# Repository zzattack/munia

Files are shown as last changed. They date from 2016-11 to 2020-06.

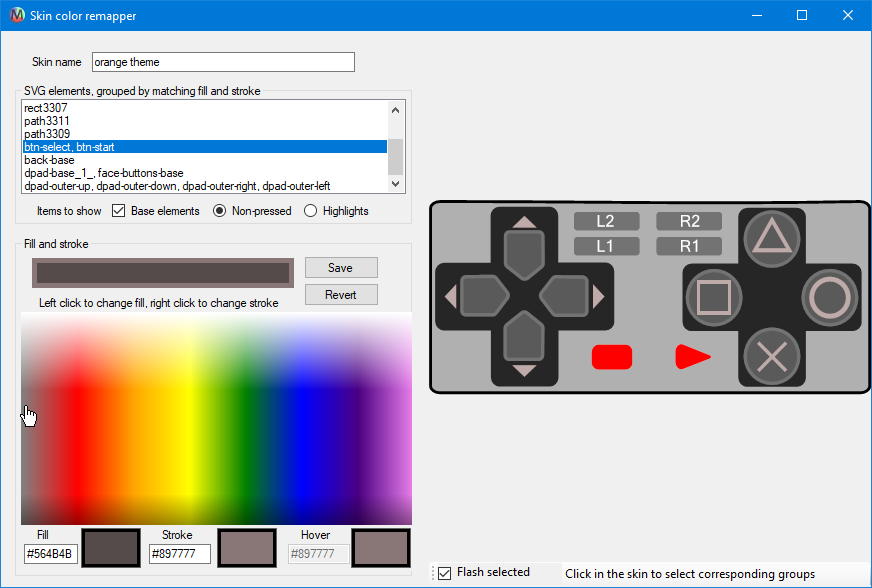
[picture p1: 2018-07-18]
munia_io/static_global/img/content/remap_engine.png

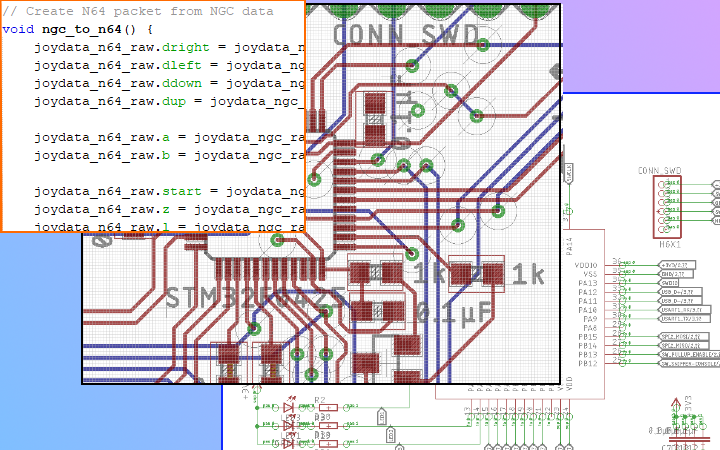
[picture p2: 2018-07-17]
munia_io/static_global/img/content/opensource.png

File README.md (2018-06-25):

MUNIA is a device that acquires input packets from controllers of various videogame consoles and shows them on your PC with the controller simultaneously remaining attached to its console. This allows you to display your inputs on gameplay videos or livestream content.
Devices for several consoles have been developed under this project:
* Nintendo Gamecube
* Sony Playstation 2
* Nintendo 64
* Super Nintendo

# Repository overview
* The hardware folder contains schematics for the various devices developed under this project. These include input adapters for Nintendo Gamecube, Nintendo 64, Super Nintendo, Sony PlayStation 2 and hybrids of the aforementioned.
* The firmware folder contains firmware projects for each of the circuit boards presented in the hardware folder.
* The munia.io folder contains the Django project powering the http://munia.io website (not functional).
* The MUNIA-win folder contains the .NET project 

## FAQ
Q. I don’t like the default skins, can I change them?
Absolutely. The software has a very strong SVG based theming engine. You can create a new one using tools like Adobe Illustrator or Inkscape. Custom XML attributes are used to map buttons to graphical elements. It’s pretty simple, honestly; take a look in SKINS.md!

Q. What does ‘MUNIA’ mean?
The very first iteration of the device supported SNES, N64 and NGC simultaneously. The acronym stands for ‘Multi-use Nintendo Input Adapter’. Both the Multi-use and Nintendo parts no longer apply to most of our devices, so we’ve parted with the acronym but kept the pretty name.

Q. Will you support console ‘X’?
Unless mentioned on the index page, the likely answer is no. Newer generation consoles are usually too complicated. The low expected demand for adapters for older generation consoles doesn’t warrant the required development investments at the moment.

Q. How does this compare to an Arduino input display?
Favorably. Benefits include not having to splice any cables, the device showing up as HID device on your computer, superior software, more stable firmware, ability to use the controller on our PC in e.g. emulators and better 3rd party controller support. In the end, though, both work and the MUNIA software also supports inputs from Arduino-based NintendoSpy devices!

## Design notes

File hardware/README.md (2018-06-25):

# This folder contains the EAGLE schematics for the various hardware boards.

## munia
This contains schematics and board layout for the 3-in-1 device with support for the Nintendo Gamecube, Nintendo 64 and Super Nintendo/SFC consoles.
The enclosure also makes use of the 

## munia-ngc
This is the simplified Gamecube-only version of the device

## munia-n64
This is the simplified N64-only version of the device

## munia-snes
This is the simplified SNES-only version of the device

## musia
This is the Sony PS2 version

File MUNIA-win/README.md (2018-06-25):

This is the .NET software which uses SVG skins and OpenGL rendering to make a powerful controller overlay for videogame streaming

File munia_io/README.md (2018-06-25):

# munia.io

These are the django project files powering the http://munia.io website.

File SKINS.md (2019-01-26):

# MUNIA skinning

Skins for MUNIA are defined as SVG files with some custom attributes mixed in to identify and animate various controller parts.
Benefits of using SVG files include perfect scaling, self-contained files and ability to use high quality image editing software such as Adobe Illustrator or [Inkscape](https://inkscape.org/).

## Process overview
1. *Find base image:* when adopting a new skin one typically begins by finding an existing image of the desired controller. For many popular controllers well-built SVG files may already exist. Should this not be the case then tracing a high quality image of said controller is a viable alternative.

2. *Add highlights:* button presses are typically shown by changing the color of said button, but MUNIA allows a lot of freedom in this aspect. Per button you normally define 2 object groups, one for the non-pressed and one for the pressed state of this button. They will typically overlap exactly, but this is not mandatory. The MUNIA software will show only one of both states at a time.

3. *Add metadata:* the last step is to add some XML attributes to the resulting .svg file. These will allow the MUNIA software to identify the various parts of the controller, and thereby animate them in the desired way. Full details on the possible attributes to specify are detailed in the sections below.

## Skin engine
The MUNIA skinning engine initially loads the SVG file, identifies the various parts in it, and caches the drawing of most individual elements. The controller with all button, stick and trigger elements removed is used as base image. All elements are continuously rendered against this base image.

### Layering
The controller is rendered as a layered image. The base image is fixed at layer '0'. Individual elements can be placed 'behind' or 'in front' of the base by specifying the `munia:z-order=x` attribute on it, where `x` can be any integer. Elements placed at layer x<0 are placed behind the base image in order of incrementing `x`. Similarly elements with positive z-order are drawn on top of the base image, again in order of incrementing `x`.

## Skin elements
Game controllers typically contain 3 kinds of elements that require some form of animation: buttons, triggers and sticks. We also need one XML element to specify what kind of controller is defined in this file. The following sections outline how to model each of them in MUNIA skins.

### Info metadata
The root `svg` element in the resulting document should contain a `munia:info` element specifying a name for the skin and the device type it is compatible with. 
Example, taken from `gc.svg` that ships with the MUNIA software:
``` xml
<munia:info munia:skin-name="Gamecube" munia:device-type="NGC"/>
```
Supported device types at the time of writing are:
* NGC
* SNES
* N64
* PS2
* XInput

### Buttons/dpad
Buttons and d-pad directions are considered identical in the MUNIA software. This simplifies skinning them. These are the relevant XML attributes:
* `munia:button-id="X"`: this specifies which button links to this image element. Refer to the final section in this document for hints on finding the correct id.
* `munia:button-state="pressed/released"`: this indicates whether this element is supposed to be visible in the pressed or released state. Effectively the software replaces the image group with `munia:button-state="released"` for the one with `button-state="pressed"` group if both have matching `munia:button-id` attributes. If you specify only one of both, the other is simply never drawn.
* `munia:z-order="x `: see Layering section above

#### Example
Taken from the SNES skin `snes-light-blue.svg` skin that ships with the software:
``` xml
<circle id="A" munia:button-id="7" munia:button-state="released" cx="380" cy="125" r="25" style="fill:#4d4d4d"/>
<circle id="A-pressed" munia:button-id="7" munia:button-state="pressed" cx="380" cy="125" r="25" style="fill:#0000ff"/>
```

### Sticks
Sticks refer to the control sticks that made their appearance in the 5th generation of videogame consoles. They are typically represented as a graphic that moves its vertical and horizontal position relative to a resting point. Sticks may also be pressable in which case you should define the button-id and button-state attributes if you want to use a different graphic for the stick depending on whether or not it is pressed. The MUNIA software implements to following attributes for specifying how these are to be rendered:

* `munia:stick-id="id"`: indicates that this element is to be considered a stick, and assigns an id to it. The id should be any unique integer number.
* `munia:axis-h="h" munia:axis-v="v"`: id's of the horizontal and vertical movement axes respectively. Refer to last section.
* `munia:offset-scale="f.f"`: a real/floating-point number indicating how far the stick moves away from its center. Good values are easily determined through trial and error. Typically a number between 0.5-2.0 should work well.
* `munia:button-id="x"`: see Buttons/dpad section above
* `munia:button-state="x"`: see Buttons/dpad section above. When using different graphics depending on the press-state, you should define the svg node describing the graphic twice; once for the pressed state and once for released. The graphic itself may of course differ in color, shape or structure.
* `munia:z-order="x"`: see Layering section above

#### Example
Taken from the Gamecube skin `gc.svg` skin that ships with the software:

``` xml
<g id="Control Stick" munia:axis-h="0" munia:axis-v="1" munia:offset-scale="1.8" transform="translate(8.6180222,-28.433458)"> ... </g>
```

### Triggers
The MUNIA software can render controller triggers as either a bar that fills up, or as an element that moves in certain direction.

* `munia:trigger-id="id"`: indicates that this element is to be considered a trigger, and assigns an id to it. The id should be any unique integer number.
* `munia:trigger-axis="x"`: id of this trigger axis on the controller. Refer to last section.
* `munia:trigger-range="a-b"`: specifies the deadzone. Defaults to '0-255' but can be limited, e.g. to '30-240' for controllers with imperfect range.
* `munia:trigger-type="bar/slide"`: whether this is rendered as a bar or slide. Bars are made partially visible, and slide-type triggers move some amount in one direction, depending on how far the trigger is pressed. 
* `munia:trigger-orientation="vertical/horizontal"`: whether the bar/slide is filled/moved in vertical or horizontal direction.
* `munia:trigger-reverse="yes/no"`: only applies to bar type triggers. When non-reversed (default), bars fill from left-to-right or top-to-bottom. Specifying `trigger-reverse="yes"` reverses that.
* `munia:trigger-inverse="yes/no"`: only applies to bar type triggers. Non-inversed triggers are 0% filled when the trigger is in resting state, and 100% filled when the trigger is entirely pressed. Inversing makes it so that not pressing the trigger reveals the entire object instead.
* `munia:offset-scale="f.f"`: applies only to *slide*-type triggers. Similar to the offset-scale attribute for sticks.
* `munia:z-order="x"`: see Layering section above

### Finding id's
One can easily find the id's of buttons and axes of a controller using the built-in `Gamepad tester` under `Tools` in the main menu.
Hat/dpad id's are mapped after the button id's, in order up/down/left/right. So if the controller has 6 face buttons and a d-pad, then the last face button has `button-id=5` and the left-direction on the d-pad is assigned `button-id=8`.

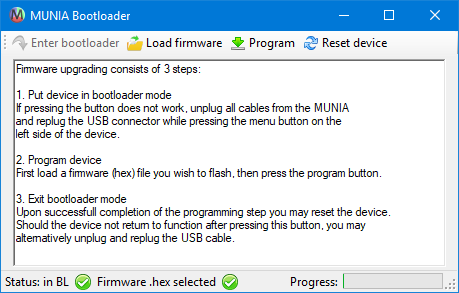
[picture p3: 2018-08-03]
munia_io/static_global/img/content/bootloader.png

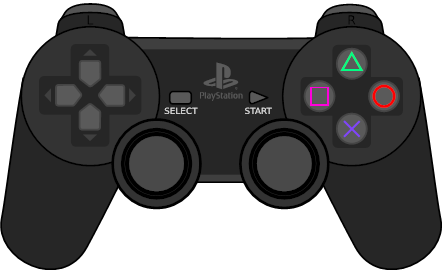
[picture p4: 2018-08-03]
munia_io/static_global/img/content/skin_ps2.png

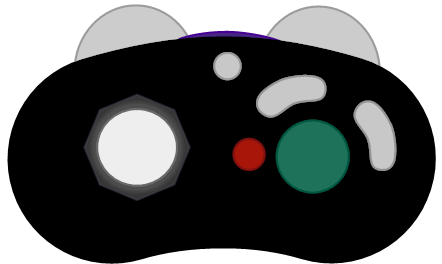
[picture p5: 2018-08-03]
munia_io/static_global/img/content/skin_gamecube_compact.png

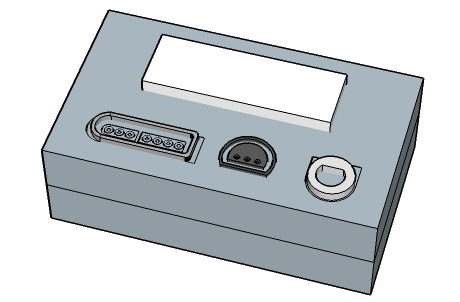
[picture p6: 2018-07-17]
munia_io/static_global/img/content/box.png

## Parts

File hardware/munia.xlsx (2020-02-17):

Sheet: components
Component | Fabrikant | Functie | Package | Datasheet
TXB0102DCUR | Texas Instruments | Level shifter | VSSOP | http://www.farnell.com/datasheets/1874809.pdf
PIC18LF24K50 | Microchip | Microcontroller | SSOP-28 | http://www.farnell.com/datasheets/1695243.pdf | x
TC1262 | Microchip | 3v3 regulator | SOT-223 | http://www.farnell.com/datasheets/1726424.pdf | x
BAT54S | NXP | Diode | SOT-23 | http://www.farnell.com/datasheets/1668625.pdf | x
BAT54C | NXP | Diode | SOT-24 | http://www.farnell.com/datasheets/1668625.pdf | x
TS3A24157DGSR | Texas Instruments | Mux | 10-MSOP | http://www.farnell.com/datasheets/1882551.pdf

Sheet: bom
Part | Quantity | Price | USB only version | Inventory | Ordered
lcd | 1 | $2.30 |  | 14 | 20
snes connector | 1 | $1.70 | $1.70 | 7 | 23
gc connector | 1 | $1.70 | $1.70 | 7 | 23
n64 connector | 1 | $1.70 | $1.70 | 7 | 23
output connector rj45 | 2 | $0.20 |  | 23 | 100
output connector rj12 | 1 | $0.20 |  | 42
usb connector | 1 | $0.20 | $0.20 | 40
pcb | 1 | $4.00 | $4.00 | 50
resistors / caps / diodes | 1 | $1.00 | $1.00 | 100
power diodes | 3 | $0.80 | $0.80 | 130
fsa2257 switch | 2 | $0.80 | $0.80 | 12 | 50
level converter gtl2010 | 1 | $0.55 | $0.55 | 38
microcontroller pic18 | 1 | $2.26 | $2.26 | 30
cable rj11 | 0.5 | $1.00 |  | 7
cable rj45 | 1 | $1.50 |  | 6
extension cable n64 | 1 | $1.60 |  | 12 | 20
extension cable gc | 1 | $1.65 |  | 8 | 20
extension cable snes | 1 | $2.10 |  | 6 | 24
internal headers/cabling | 10 | $1.60 | $1.60 | 50
3.3v regulator tc1262 | 1 | $0.44 | $0.44 | 99999
enclosure | 1 | $3.00 | $3.00 | 10 | 20
total |  | $30.30 | $19.75

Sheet: proto
idx | value |  | source
0 | 0 |  | wii
1 | 1 |  | wii
2 | 0 |  | wii
3 | 0 |  | wii
4 | 0 |  | wii
5 | 0 |  | wii
6 | 0 |  | wii
7 | 0 |  | wii
8 | 0 |  | wii
9 | 0 |  | wii
10 | 0 |  | wii
11 | 0 |  | wii
12 | 0 |  | wii
13 | 0 |  | wii
14 | 1 |  | wii
15 | 1 |  | wii
16 | 0 |  | wii
17 | 0 |  | wii
18 | 0 |  | wii
19 | 0 |  | wii
20 | 0 |  | wii
21 | 0 |  | wii | 0/1
22 | 0 |  | wii
23 | 0 |  | wii
24 | 1 |  |  | stop bit
25 | 0 |  | controller | always 0
26 | 0 |  | controller | always 0
27 | 0 |  | controller | 0 or 1
28 | 0 |  | controller | start
29 | 0 |  | controller | y
30 | 0 |  | controller | x
31 | 0 |  | controller | b
32 | 0 |  | controller | always 0
33 | 1 |  | controller | always 1
34 | 0 |  | controller | L
35 | 0 |  | controller | R
36 | 0 |  | controller | z
37 | 0 |  | controller | dup
38 | 0 |  | controller | ddown
39 | 0 |  | controller | dright
40 | 0 |  | controller | dleft
41 | 1 |  | controller | joyx
42 | 0 |  | controller | joyx
43 | 0 |  | controller | joyx
44 | 0 |  | controller | joyx
45 | 0 |  | controller | joyx
46 | 1 |  | controller | joyx
47 | 0 |  | controller | joyx
48 | 0 |  | controller | joyx
49 | 1 |  | controller | joyy
50 | 0 |  | controller | joyy
51 | 0 |  | controller | joyy
52 | 0 |  | controller | joyy
53 | 1 |  | controller | joyy
54 | 1 |  | controller | joyy
55 | 0 |  | controller | joyy
56 | 0 |  | controller | joyy
57 | 0 |  | controller | cx
58 | 1 |  | controller | cx
59 | 1 |  | controller | cx
60 | 1 |  | controller | cx
61 | 1 |  | controller | cx
62 | 0 |  | controller | cx
63 | 1 |  | controller | cx
64 | 1 |  | controller | cx
65 | 1 |  | controller | cy
66 | 0 |  | controller | cy
67 | 0 |  | controller | cy
68 | 0 |  | controller | cy
69 | 0 |  | controller | cy
70 | 0 |  | controller | cy
71 | 0 |  | controller | cy
72 | 1 |  | controller | cy
73 | 0 |  | controller | ltrig
74 | 0 |  | controller | ltrig
75 | 0 |  | controller | ltrig
76 | 1 |  | controller | ltrig
77 | 0 |  | controller | ltrig
78 | 1 |  | controller | ltrig
79 | 1 |  | controller | ltrig
80 | 0 |  | controller | ltrig
81 | 0 |  | controller | rtrig
82 | 0 |  | controller | rtrig
83 | 0 |  | controller | rtrig
84 | 0 |  | controller | rtrig
85 | 0 |  | controller | rtrig
86 | 0 |  | controller | rtrig
87 | 0 |  | controller | rtrig
88 | 0 |  | controller | rtrig
89 | 0 | 0x00 |  | stop bit

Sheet: power
operation mode
input | output | available power | required output | possible | 3v3 level | 5v level | controller power source
gc | gc | 5v | 5v, 3v3 | yes | 3v3 | 4.8v
gc | n64 | 3v3 | 5v, 3v3 | needs usb | 3v3 | 0v
gc | snes | 5v | 5v, 3v3 | yes | 3v3 | 4.8v
n64 | gc | 5v | 3v3 | yes | 3v1 | 4.8v
n64 | n64 | 3v3 | 3v3 | maybe | 3v3 | 0v
n64 | snes | 5v | 3v3 |  | 3v3 | 4.8v
snes | gc | 5v | 5v, 3v3 |  |  | 4.8v
snes | n64 | 3v3 | 5v, 3v3 |  | 3v1 | 0v
snes | snes | 5v | 5v, 3v3 |  |  | 4.8v

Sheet: cables
SNES and NGC pinout on RJ45
Pin | RJ45 color | Function | NGC cable 1 | NGC cable 2 | NGC cable 3 | NGC cable 4 | SNES cable 1 | SNES cable 2 | SNES cable 3
1 | White/orange | SNES-5v |  |  |  |  | Blue | Green | Blue
2 | Orange | SNES-clk |  |  |  |  | Yellow | Yellow | Yellow
3 | White/green | SNES-latch |  |  |  |  | Black | White | White
4 | Blue | CSNES-dat |  |  |  |  | Red | Red | Red
5 | White/blue | CGC-dat | White | Yellow | Orange | Red
6 | Green | NC | Blue
7 | White/brown | 5v-NGC | Red | Black | Brown | White
8 | Brown | GND | Yellow, Black | Red | Black | Yellow, Black | Green | Black | Brown
 |  |  | w/ brown wire | w/o brown wire | 7 conductors | 5 conductor |  | w/ white wire
N64 pinout on phone connector
N64 cable |  | Function | RJ10 pin | RJ11 pin
 |  |  |  | 1
 |  |  | 1 | 2
Black |  | GND | 2 | 3
Green/White |  | DATA | 3 | 4
Red |  | 3v3 | 4 | 5
 |  |  |  | 6
NGC pinout on 6-pin
Pin | Color | Function | breakout
1 | Green | MGND | 4
2 | Orange | GND | 3
3 | Yellow | GND | 7
4 | White | DAT | 2
5 | Red | 3v3 | 6
6 | Black | 5v | 1
N64 pinout on header
Pin |  | Function | connector
1 | Red | 3v3 | 1
2 | Black | DATA | 2
3 | Yellow | GND | 3
 | On rev3: swap pins 1 and 3 on header!!
SNES pinout on 5-pin
Pin | Color | Function | SNES cable 1 | SNES cable 2 | SNES cable 3 | connector
1 | Orange | GND | Green | Green | Brown | 7
2 | Yellow | CLK | Yellow | Yellow | Yellow | 2
3 | White | LATCH | Black | White | White | 3
4 | Red | DATA | Red | Red | Red | 4
5 | Black | 5V | Blue | Black | Blue | 1
PS2 pinout on RJ45
Pin | Color | Function | RJ45
1 | Brown | Data | 1
2 | Orange | Command | 2
3 | White/Grey | Rumble | 3
4 | Black | Ground | 4
5 | Red | 3v3 | 5
6 | Yellow | Attention | 6
7 | Blue | Clock | 7
8 | Green | Acknowledge | 8

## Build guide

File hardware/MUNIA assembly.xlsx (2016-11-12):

ENCLOSURE
1. clean enclosure (dust/shit) | 2
2. setup CAM for CNC machine for top cover drills | 15
3. load part into CNC, setup & run | 3
4. setup CAM for CNC machine to ethernet plugs | 15
5. load part into CNC, setup & run | 3
6. clean dust and crap | 2
PCB PREP
0. have all components in inventory. not having them will cause additional hand soldering requirement later on.
1. apply solder paste to PCB | 2
2. place all SMD components on PCB (microcontroller, level shifters, analog switches, resistors, caps, voltage regulator, diodes) | 10
3. setup reflow oven, run PCB through it | 5
4. inspect, fixup unintended bridges | 2
5. solder all connectors/headers onto PCB | 5
6. program microcontroller using pickit | 2
TOP COVER / BOTTOM COVER
1. Solder connector PCB to NGC/NGC/SNES case-mount connectors. Especially NGC is tricky due to small contacts | 15
2. Solder header wires to connector PCB's; according to schematic | 15
3. Fix connector to enclosure, using hot-glue | 5
4. Solder 8-pin and 4-pin headers to LCD module | 3
5. Glue LCD in top cover | 1
6. Drill 3mm power led, aligned left/vertical center to LCD | 1
7. Drill 6.5mm hole in bottom part of enclosure for menu button | 2
8. Push in power led and menu button | 3
9. Solder ground of power led to one side of menu button switch | 1
10. Solder 3-pin header to power led/menu switch | 1
11. Glue down led | 1
CABLES
1. Cut off female end of SNES/N64/NGC connector | 1
2. Strip cable properly | 2
3. Use document to find connector pinout | 2
4. Crimp RJ10/RJ45 properly to stripped wires | 1
FINISH
1. Test everything | 5
2. Glue PCB to bottom part of enclosure | 2
3. Tuck away wires and screw everything shut | 2
total time | 129 | minutes
without setup | 99

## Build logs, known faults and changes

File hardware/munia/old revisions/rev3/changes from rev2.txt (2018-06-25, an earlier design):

rev3 changes from rev2:
- more space between 4 and 8 pin header for LCD
- route power trace more inward near LCD headers
- change big electrolytic capacitor for 1206 tantalum
- finally align the enclosure drill holes correctly
- changed contrast resistor from 2k to 2k2
- removed 3.3v output to rj45 connectors
- swapped pin 1 and 3 on N64 connector for unity
- reverse lcd power header
- reversed lcd d4-d7 connections on header
- icsp header more to the left so pickit fits
- silk text further away from headers
- slightly larger drills for ethernet leds (0.6-->0.9mm)
- remove extra grounds from ngc connector

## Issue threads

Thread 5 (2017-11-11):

GCN --> N64: must unplug N64 controller to use the GCN controller in GCN-->N64 mode

valandil, 2017-11-11:
Firmware version: 1.5
HW revision: rev2
Microcontroller: 0x5c20
µC revision: 2

As the title says, to be able to use the Gamecube controller on N64, I have to start the MUNIA with both the N64 and GCN controller plugged in, and then unplug the N64 controller and switch to the GCN controller in the MUNIA config.

I assume that the intended behaviour is that input from the GCN controller is always polled, regardless of the MUNIA config in the software, and regardless of whether the N64 controller is plugged in. I also assume that the MUNIA config dialog should only impact which controller the input display uses, not select the inputs that are sent to the actual N64 console. Is that correct?

If not, is it possible to implement this behaviour? To be, this would be a good default configuration. It would be even better if the input display could read inputs from multiple controllers at once, but if I'm not mistaken that's not possible, at least right now?

valandil, 2017-12-11:
This also happens with firmware 1.6. My N64 is a NUS-001, if that matters.

valandil, 2018-04-25:
I think I only tested with SM64. I can test with other games, although from what you're saying, the behaviour I'm looking for is impossible to achieve with the MUNIA. It's good to know for sure, at least!

zzattack, 2018-04-25:
It might be possible if we inspect the partial frame sent on initialization
of the n64 controller. I'll have to dig into that.

On Wed, Apr 25, 2018 at 3:50 PM, Joey Dumont <notifications@github.com>
wrote:

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

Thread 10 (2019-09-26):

Z order doesn't seem to apply to dual-stick mappings

ComplexPlane, 2019-09-26:
Hello,

I'm trying to create an effect where two paths are both mapped to the same stick, but one path shows at layer -1 while the other one shows at layer 1. There's a black mask at layer 0 that the layer at -1 is supposed to show through.

[Sample](https://gist.github.com/ComplexPlane/9782650f914e929d69e045c29d3cb353)

The paths in question have a `munia:z-order` attribute.

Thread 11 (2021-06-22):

[Suggestion] Linux Build

Roadhog360, 2021-06-22:
Recently bought one of those adapters for NintendoSpy. When I switched to Linux I noticed NintendoSpy is not working with Wine, and neither is MUNIA when I found it. I'm really hoping this gets a Linux build as no other alternative I've tried works at all and asking for Linux builds of those are futile, as it's either they've stopped development years ago, say they support Linux but the Linux builds are clearly untested because they don't work at all, or both.

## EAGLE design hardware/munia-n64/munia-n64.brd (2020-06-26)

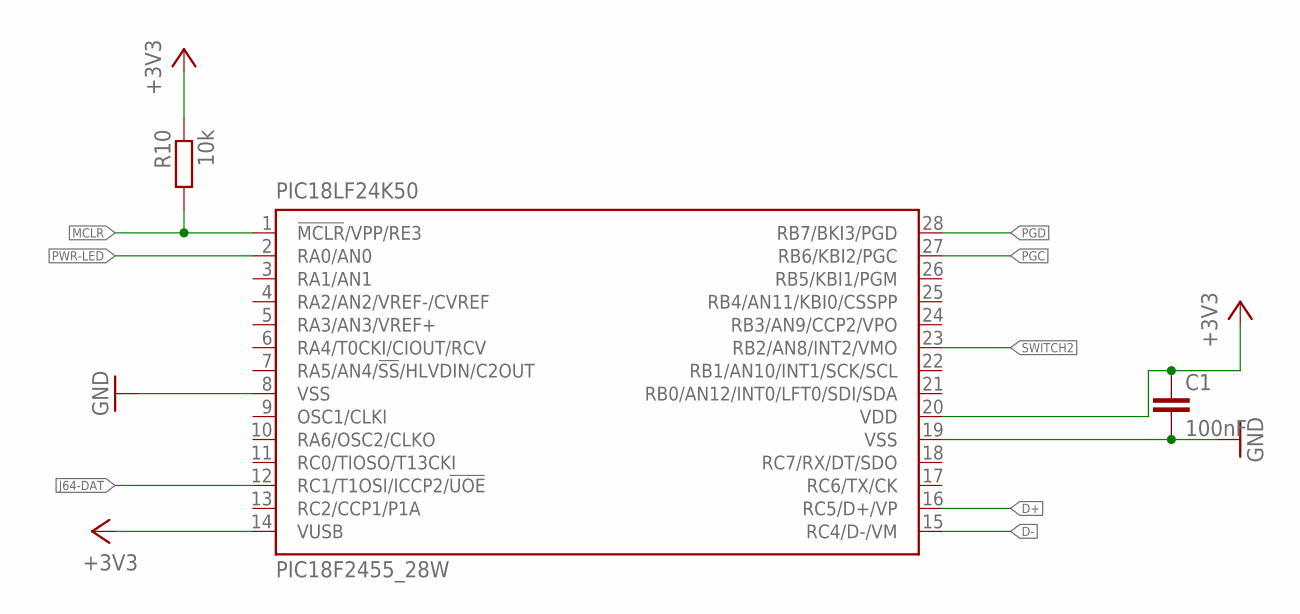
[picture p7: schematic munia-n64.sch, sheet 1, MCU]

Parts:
C1: 100nF; C0603
PIC18LF24K50: PIC18F2455_28W; SO28W
R10: 10k; R0603

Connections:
+3V3: C1.1, PIC18LF24K50.14 (VUSB), PIC18LF24K50.20 (VDD), R10.1; also elsewhere on the board
D+: PIC18LF24K50.16 (RC5/D+/VP); also elsewhere on the board
D-: PIC18LF24K50.15 (RC4/D-/VM); also elsewhere on the board
GND: C1.2, PIC18LF24K50.8 (VSS), PIC18LF24K50.19 (VSS); also elsewhere on the board
J64-DAT: PIC18LF24K50.12 (RC1/T1OSI/ICCP2/!UOE); also elsewhere on the board
MCLR: PIC18LF24K50.1 (!MCLR!/VPP/RE3), R10.2; also elsewhere on the board
PGC: PIC18LF24K50.27 (RB6/KBI2/PGC); also elsewhere on the board
PGD: PIC18LF24K50.28 (RB7/BKI3/PGD); also elsewhere on the board
PWR-LED: PIC18LF24K50.2 (RA0/AN0); also elsewhere on the board
SWITCH2: PIC18LF24K50.23 (RB2/AN8/INT2/VMO)

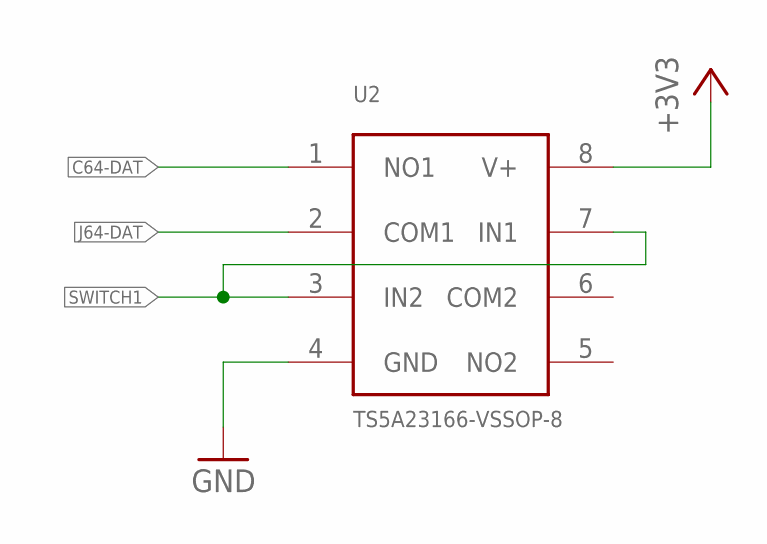
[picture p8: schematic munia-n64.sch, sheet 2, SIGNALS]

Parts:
U2: TS5A23166-VSSOP-8; SOT765

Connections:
+3V3: U2.8 (V+); also elsewhere on the board
C64-DAT: U2.1 (NO1); also elsewhere on the board
GND: U2.4 (GND); also elsewhere on the board
J64-DAT: U2.2 (COM1); also elsewhere on the board
SWITCH1: U2.3 (IN2), U2.7 (IN1)

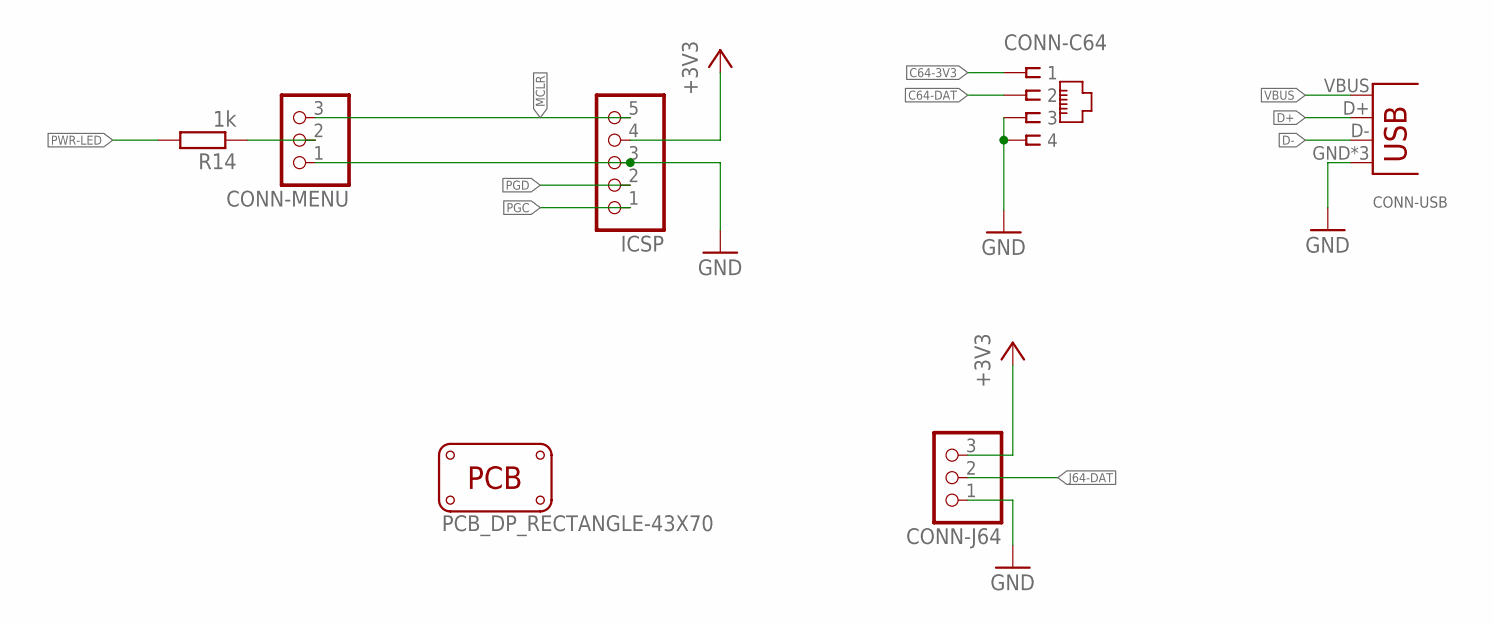
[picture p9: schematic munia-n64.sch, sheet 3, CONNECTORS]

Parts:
CONN-C64: RJ11-6P4C; RJ11-4C
CONN-J64: PINHD-1X3; 1X03
CONN-MENU: PINHD-1X3; 1X03
CONN-USB: USB-B-NIELS; USB-B-H
ICSP: PINHD-1X5; 1X05
PCB1: PCB_DP_RECTANGLE-43X70; DP7043_V1
R14: 1k; R0603

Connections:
+3V3: CONN-J64.3, ICSP.4; also elsewhere on the board
C64-3V3: CONN-C64.1; also elsewhere on the board
C64-DAT: CONN-C64.2; also elsewhere on the board
D+: CONN-USB.D+; also elsewhere on the board
D-: CONN-USB.D-; also elsewhere on the board
GND: CONN-C64.3, CONN-C64.4, CONN-J64.1, CONN-MENU.1, CONN-USB.GND, CONN-USB.GND@1 (GND), CONN-USB.GND@2 (GND), ICSP.3; also elsewhere on the board
J64-DAT: CONN-J64.2; also elsewhere on the board
MCLR: CONN-MENU.3, ICSP.5; also elsewhere on the board
unnamed: CONN-MENU.2, R14.1
PGC: ICSP.1; also elsewhere on the board
PGD: ICSP.2; also elsewhere on the board
PWR-LED: R14.2; also elsewhere on the board
VBUS: CONN-USB.VBUS; also elsewhere on the board

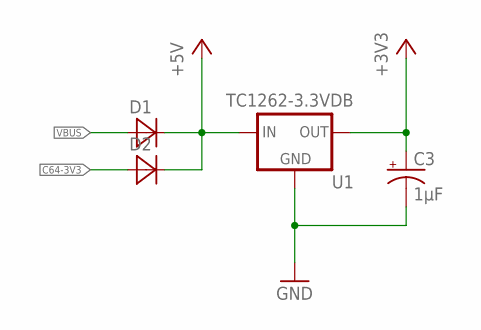
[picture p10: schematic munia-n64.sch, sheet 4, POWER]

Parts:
C3: 1µF; EIA3216
D1, D2: MBR120VLSFT1G; SOD123
U1: TC1262-3.3VDB; SOT230P700X180-4N

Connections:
+3V3: C3.A (+), U1.3 (OUT); also elsewhere on the board
+5V: D1.1 (C), D2.1 (C), U1.1 (IN)
C64-3V3: D2.2 (A); also elsewhere on the board
GND: C3.C (-), U1.2 (GND), U1.4 (GND); also elsewhere on the board
VBUS: D1.2 (A); also elsewhere on the board

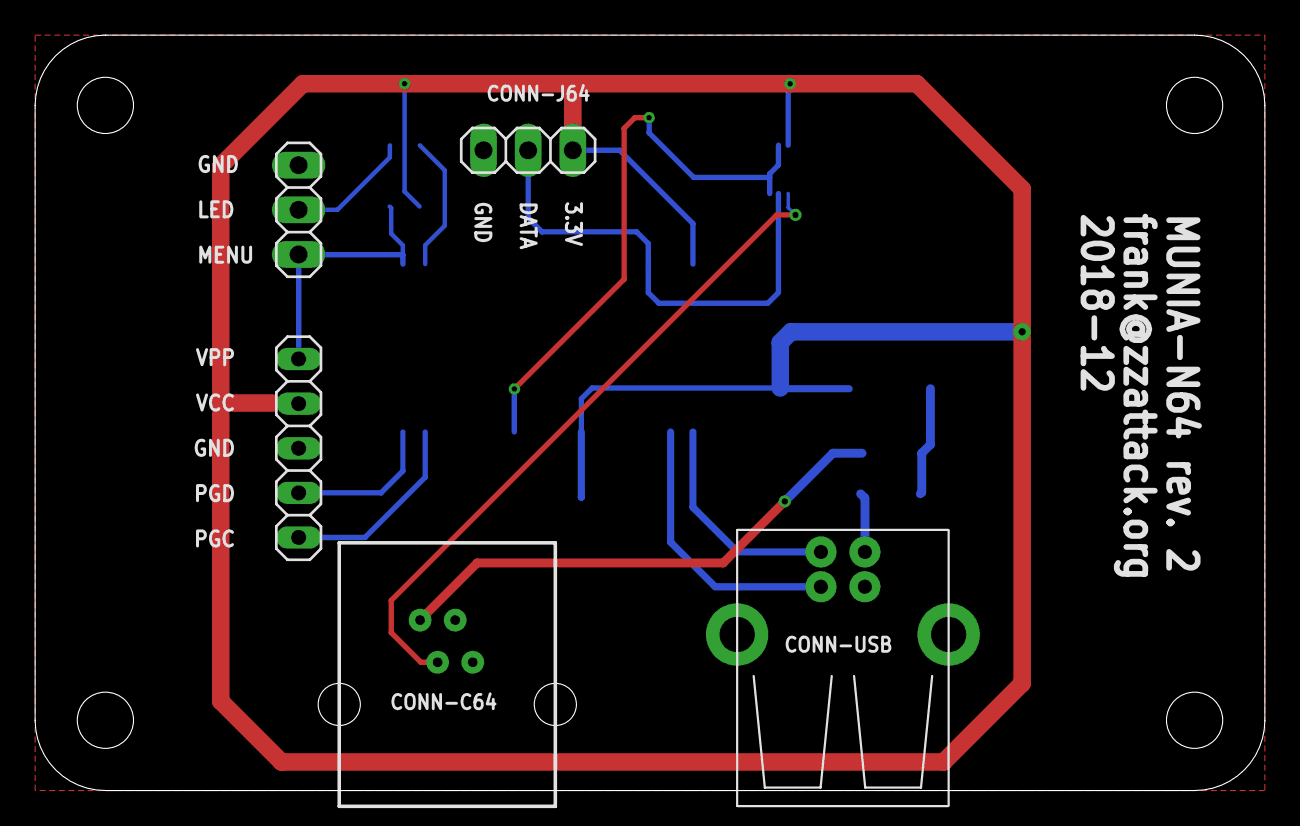
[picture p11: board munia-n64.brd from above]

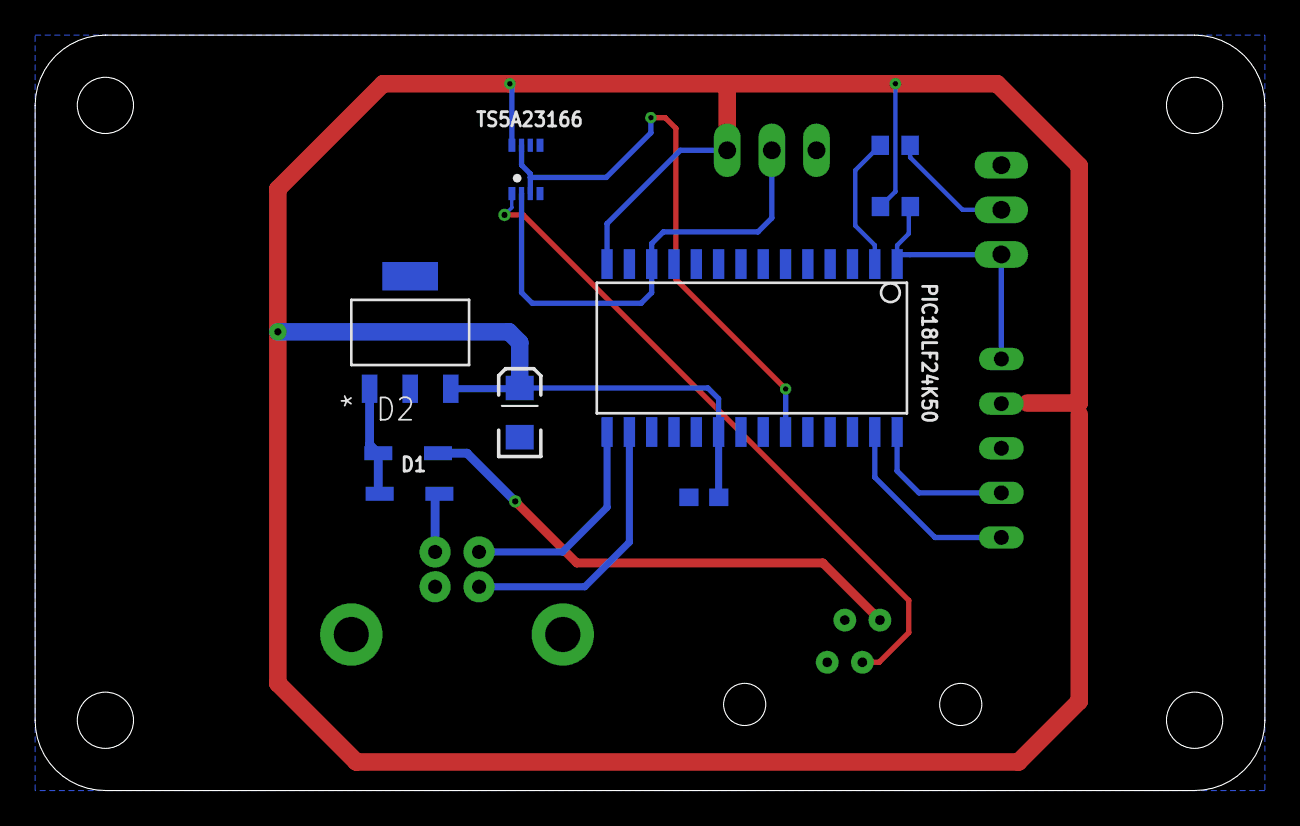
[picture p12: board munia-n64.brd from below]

Board: 2 copper layers, 70.0 x 43.0 mm, 15 parts (9 on the bottom side), 15 nets.

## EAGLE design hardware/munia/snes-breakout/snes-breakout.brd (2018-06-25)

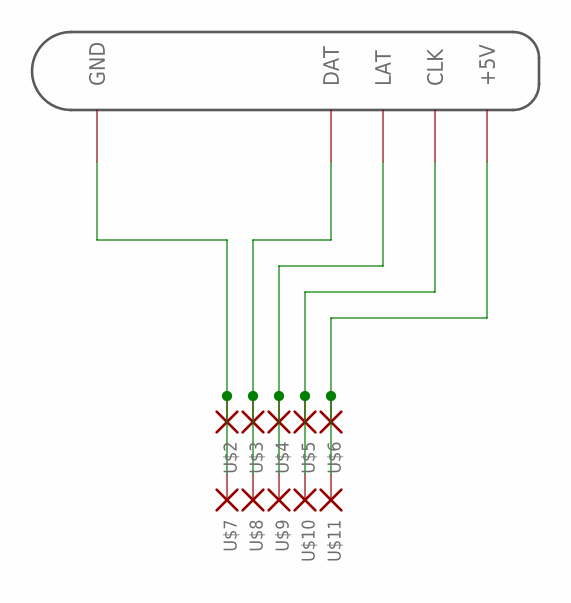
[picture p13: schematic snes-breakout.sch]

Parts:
U$1: SNES-CONNECTOR
U$2, U$3, U$4, U$5, U$6, U$7, U$8, U$9, U$10, U$11: SMDPADSMD6080; SMD6080

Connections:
CLK: U$1.P$6 (CLK), U$5.P$1, U$10.P$1
DAT: U$1.P$4 (DAT), U$3.P$1, U$8.P$1
GND: U$1.P$1 (GND), U$2.P$1, U$7.P$1
LAT: U$1.P$5 (LAT), U$4.P$1, U$9.P$1
VCC: U$1.P$7 (+5V), U$6.P$1, U$11.P$1

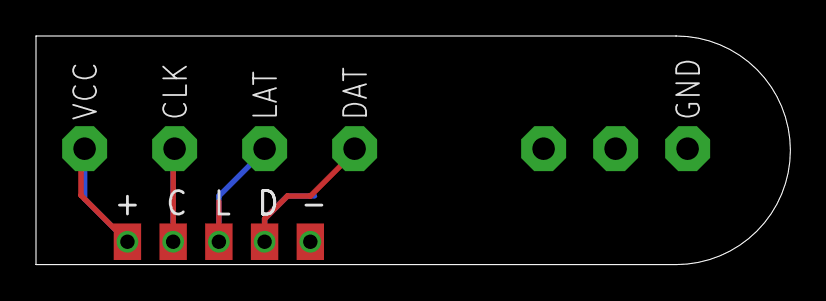
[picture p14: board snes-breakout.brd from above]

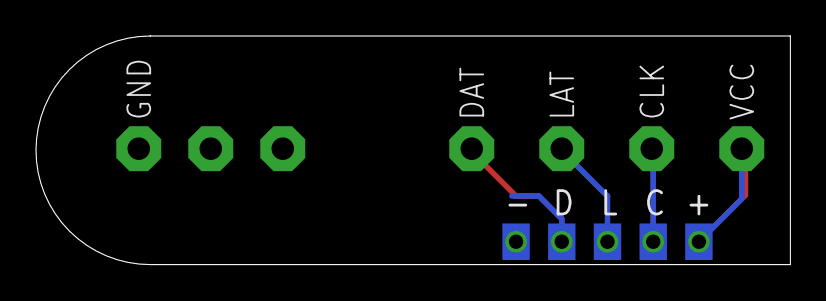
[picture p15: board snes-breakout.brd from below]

Board: 2 copper layers, 41.9 x 12.7 mm, 11 parts (5 on the bottom side), 5 nets.

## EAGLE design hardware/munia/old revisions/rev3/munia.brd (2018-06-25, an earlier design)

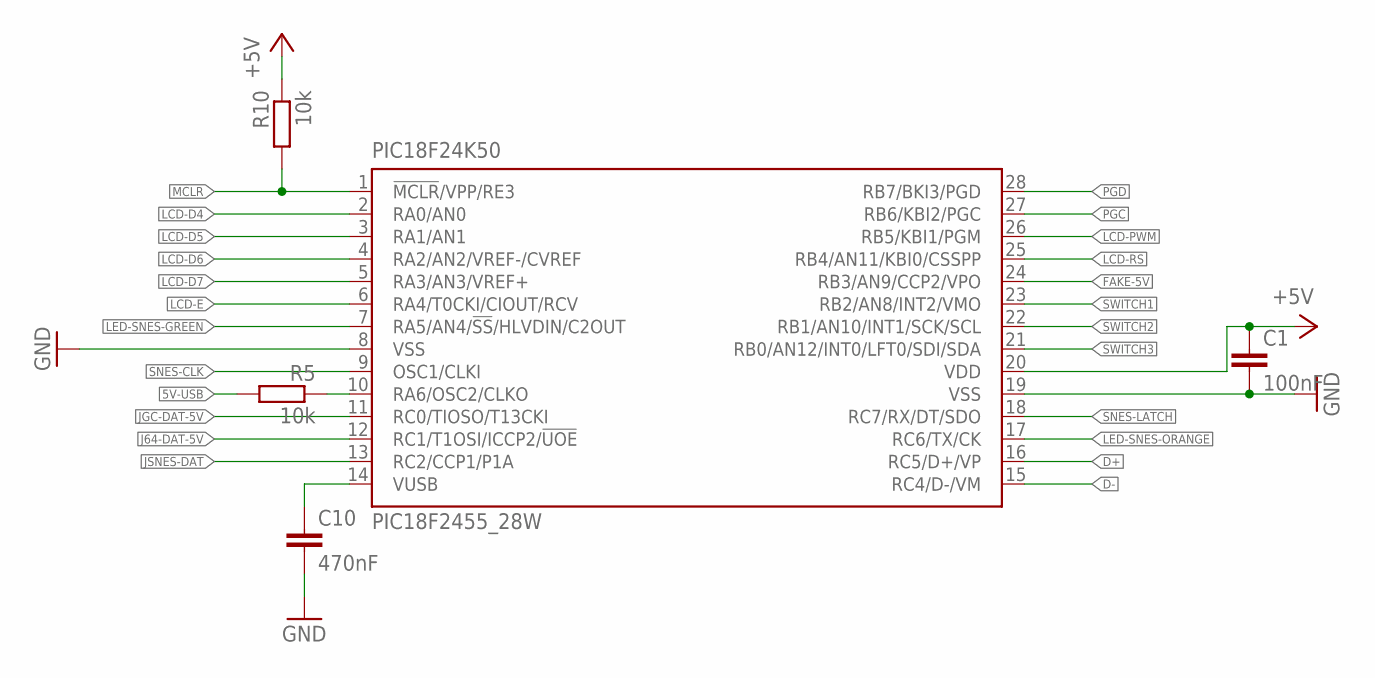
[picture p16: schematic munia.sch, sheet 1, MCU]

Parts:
C1: 100nF; C0603
C10: 470nF; C0603
PIC18F24K50: PIC18F2455_28W; SO28W
R5, R10: 10k; R0603

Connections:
5V-USB: R5.2; also elsewhere on the board
+5V: C1.1, PIC18F24K50.20 (VDD), R10.1; also elsewhere on the board
D+: PIC18F24K50.16 (RC5/D+/VP); also elsewhere on the board
D-: PIC18F24K50.15 (RC4/D-/VM); also elsewhere on the board
FAKE-5V: PIC18F24K50.24 (RB3/AN9/CCP2/VPO); also elsewhere on the board
GND: C1.2, C10.2, PIC18F24K50.8 (VSS), PIC18F24K50.19 (VSS); also elsewhere on the board
J64-DAT-5V: PIC18F24K50.12 (RC1/T1OSI/ICCP2/!UOE); also elsewhere on the board
JGC-DAT-5V: PIC18F24K50.11 (RC0/TIOSO/T13CKI); also elsewhere on the board
JSNES-DAT: PIC18F24K50.13 (RC2/CCP1/P1A); also elsewhere on the board
LCD-D4: PIC18F24K50.2 (RA0/AN0); also elsewhere on the board
LCD-D5: PIC18F24K50.3 (RA1/AN1); also elsewhere on the board
LCD-D6: PIC18F24K50.4 (RA2/AN2/VREF-/CVREF); also elsewhere on the board
LCD-D7: PIC18F24K50.5 (RA3/AN3/VREF+); also elsewhere on the board
LCD-E: PIC18F24K50.6 (RA4/T0CKI/CIOUT/RCV); also elsewhere on the board
LCD-PWM: PIC18F24K50.26 (RB5/KBI1/PGM); also elsewhere on the board
LCD-RS: PIC18F24K50.25 (RB4/AN11/KBI0/CSSPP); also elsewhere on the board
LED-SNES-GREEN: PIC18F24K50.7 (RA5/AN4/!SS!/HLVDIN/C2OUT); also elsewhere on the board
LED-SNES-ORANGE: PIC18F24K50.17 (RC6/TX/CK); also elsewhere on the board
MCLR: PIC18F24K50.1 (!MCLR!/VPP/RE3), R10.2; also elsewhere on the board
unnamed: C10.1, PIC18F24K50.14 (VUSB)
PGC: PIC18F24K50.27 (RB6/KBI2/PGC); also elsewhere on the board
PGD: PIC18F24K50.28 (RB7/BKI3/PGD); also elsewhere on the board
SNES-CLK: PIC18F24K50.9 (OSC1/CLKI); also elsewhere on the board
SNES-LATCH: PIC18F24K50.18 (RC7/RX/DT/SDO); also elsewhere on the board
SWITCH1: PIC18F24K50.23 (RB2/AN8/INT2/VMO); also elsewhere on the board
SWITCH2: PIC18F24K50.22 (RB1/AN10/INT1/SCK/SCL); also elsewhere on the board
SWITCH3: PIC18F24K50.21 (RB0/AN12/INT0/LFT0/SDI/SDA); also elsewhere on the board
USB-SENSE: PIC18F24K50.10 (RA6/OSC2/CLKO), R5.1

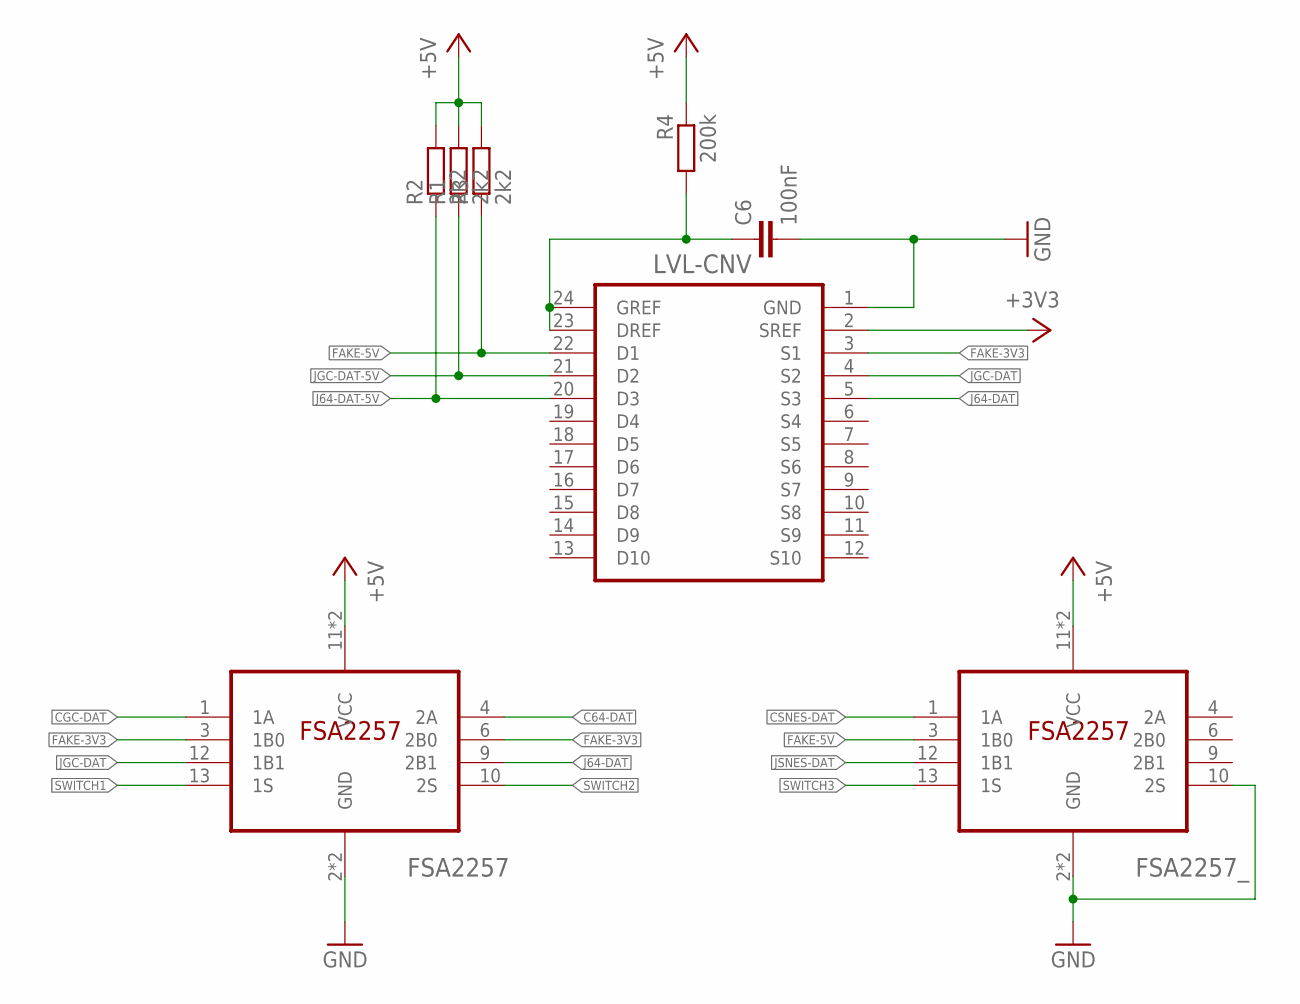
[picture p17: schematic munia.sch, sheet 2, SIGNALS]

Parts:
C6: 100nF; C0603
FSA2257, FSA2257_: FSA2257MTCX; TSSOP14
LVL-CNV: GTL2010; TSSOP24
R1, R2, R3: 2k2; R0603
R4: 200k; R0603

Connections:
+3V3: LVL-CNV.2 (SREF); also elsewhere on the board
+5V: FSA2257.11 (VCC), FSA2257.14 (VCC), FSA2257_.11 (VCC), FSA2257_.14 (VCC), R1.2, R2.2, R3.2, R4.1; also elsewhere on the board
C64-DAT: FSA2257.4 (2A); also elsewhere on the board
CGC-DAT: FSA2257.1 (1A); also elsewhere on the board
CSNES-DAT: FSA2257_.1 (1A); also elsewhere on the board
FAKE-3V3: FSA2257.3 (1B0), FSA2257.6 (2B0), LVL-CNV.3 (S1)
FAKE-5V: FSA2257_.3 (1B0), LVL-CNV.22 (D1), R3.1; also elsewhere on the board
GND: C6.2, FSA2257.2 (GND), FSA2257.5 (GND), FSA2257_.2 (GND), FSA2257_.5 (GND), FSA2257_.10 (2S), LVL-CNV.1 (GND); also elsewhere on the board
J64-DAT: FSA2257.9 (2B1), LVL-CNV.5 (S3); also elsewhere on the board
J64-DAT-5V: LVL-CNV.20 (D3), R2.1; also elsewhere on the board
JGC-DAT: FSA2257.12 (1B1), LVL-CNV.4 (S2); also elsewhere on the board
JGC-DAT-5V: LVL-CNV.21 (D2), R1.1; also elsewhere on the board
JSNES-DAT: FSA2257_.12 (1B1); also elsewhere on the board
unnamed: C6.1, LVL-CNV.23 (DREF), LVL-CNV.24 (GREF), R4.2
SWITCH1: FSA2257.13 (1S); also elsewhere on the board
SWITCH2: FSA2257.10 (2S); also elsewhere on the board
SWITCH3: FSA2257_.13 (1S); also elsewhere on the board

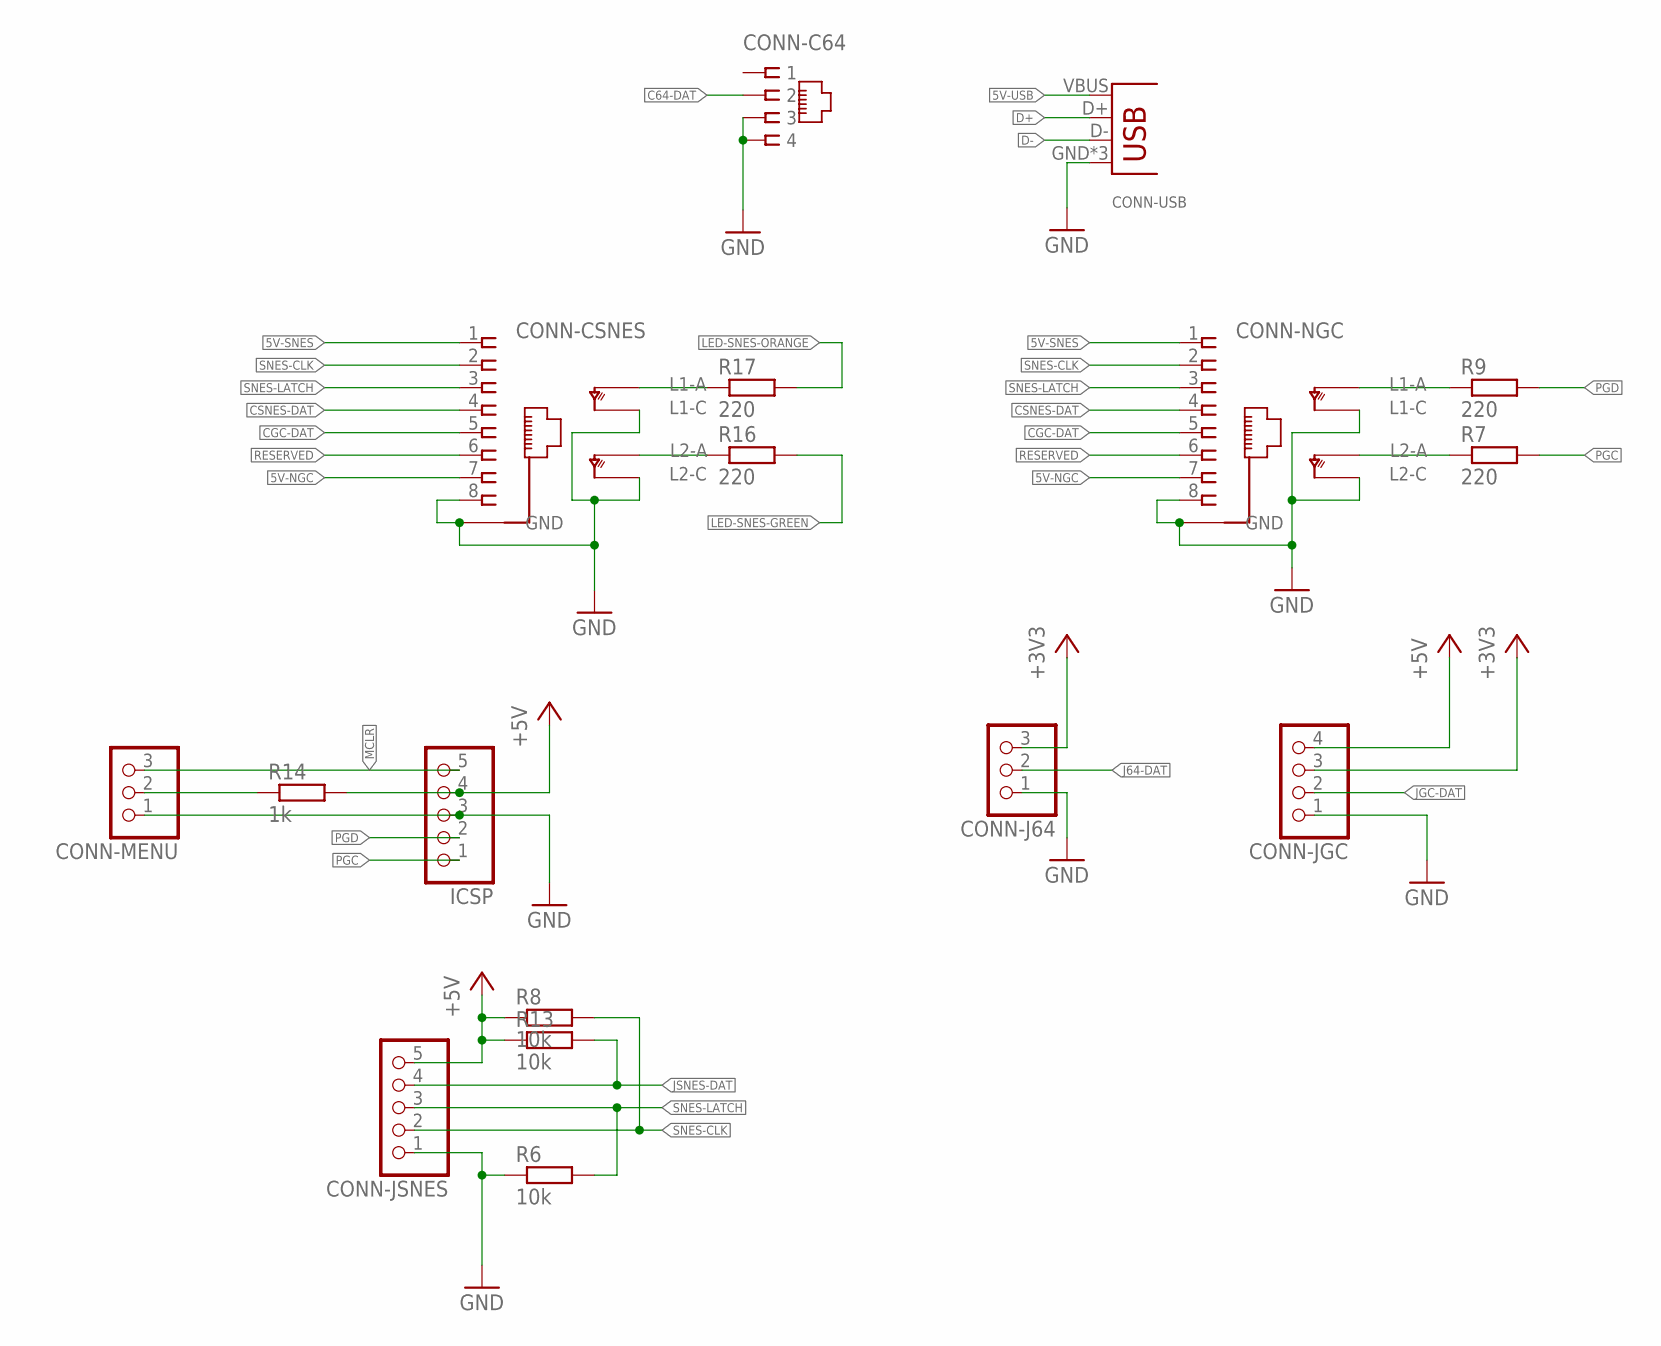
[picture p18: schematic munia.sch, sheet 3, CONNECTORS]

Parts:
CONN-C64: RJ11-6P4C; RJ11-4C
CONN-CSNES: RJ45-NIELS
CONN-J64: PINHD-1X3; 1X03
CONN-JGC: PINHD-1X4; 1X04
CONN-JSNES: PINHD-1X5; 1X05
CONN-MENU: PINHD-1X3; 1X03
CONN-NGC: RJ45-NIELS
CONN-USB: USB-B-NIELS; USB-B-H
ICSP: PINHD-1X5; 1X05
R6, R8, R13: 10k; R0603
R7, R9, R16, R17: 220; R0603
R14: 1k; R0603

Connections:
5V-NGC: CONN-CSNES.7, CONN-NGC.7; also elsewhere on the board
5V-SNES: CONN-CSNES.1, CONN-NGC.1; also elsewhere on the board
5V-USB: CONN-USB.VBUS; also elsewhere on the board
+3V3: CONN-J64.3, CONN-JGC.3; also elsewhere on the board
+5V: CONN-JGC.4, CONN-JSNES.5, ICSP.4, R8.1, R13.1, R14.2; also elsewhere on the board
C64-DAT: CONN-C64.2; also elsewhere on the board
CGC-DAT: CONN-CSNES.5, CONN-NGC.5; also elsewhere on the board
CSNES-DAT: CONN-CSNES.4, CONN-NGC.4; also elsewhere on the board
D+: CONN-USB.D+; also elsewhere on the board
D-: CONN-USB.D-; also elsewhere on the board
GND: CONN-C64.3, CONN-C64.4, CONN-CSNES.8, CONN-CSNES.GND@5 (GND), CONN-CSNES.GND@6 (GND), CONN-CSNES.LED-GREEN-C (L2C), CONN-CSNES.LED-ORANGE-C (L1C), CONN-J64.1, CONN-JGC.1, CONN-JSNES.1, CONN-MENU.1, CONN-NGC.8, CONN-NGC.GND@5 (GND), CONN-NGC.GND@6 (GND), CONN-NGC.LED-GREEN-C (L2C), CONN-NGC.LED-ORANGE-C (L1C), CONN-USB.GND, CONN-USB.GND@1 (GND), CONN-USB.GND@2 (GND), ICSP.3, R6.1; also elsewhere on the board
J64-DAT: CONN-J64.2; also elsewhere on the board
JGC-DAT: CONN-JGC.2; also elsewhere on the board
JSNES-DAT: CONN-JSNES.4, R13.2; also elsewhere on the board
LED-SNES-GREEN: R16.2; also elsewhere on the board
LED-SNES-ORANGE: R17.2; also elsewhere on the board
MCLR: CONN-MENU.3, ICSP.5; also elsewhere on the board
unnamed: CONN-CSNES.LED-ORANGE-A (L1A), R17.1
unnamed: CONN-CSNES.LED-GREEN-A (L2A), R16.1
unnamed: CONN-NGC.LED-ORANGE-A (L1A), R9.1
unnamed: CONN-NGC.LED-GREEN-A (L2A), R7.1
PGC: ICSP.1, R7.2; also elsewhere on the board
PGD: ICSP.2, R9.2; also elsewhere on the board
PWR-LED: CONN-MENU.2, R14.1
RESERVED: CONN-CSNES.6, CONN-NGC.6
SNES-CLK: CONN-CSNES.2, CONN-JSNES.2, CONN-NGC.2, R8.2; also elsewhere on the board
SNES-LATCH: CONN-CSNES.3, CONN-JSNES.3, CONN-NGC.3, R6.2; also elsewhere on the board


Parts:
BC547: BC847; SOT23
LCD-DATA: PINHD-1X8; 1X08
LCD-PWR: PINHD-1X4; 1X04
R11: 1k; R0603
R12: 2k2; R0603

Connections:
+5V: LCD-DATA.7, LCD-PWR.2; also elsewhere on the board
C: BC547.3 (C), LCD-DATA.8
GND: BC547.2 (E), LCD-DATA.1, LCD-PWR.1, R12.1; also elsewhere on the board
LCD-D4: LCD-DATA.3; also elsewhere on the board
LCD-D5: LCD-DATA.4; also elsewhere on the board
LCD-D6: LCD-DATA.5; also elsewhere on the board
LCD-D7: LCD-DATA.6; also elsewhere on the board
LCD-E: LCD-DATA.2; also elsewhere on the board
LCD-PWM: R11.2; also elsewhere on the board
LCD-RS: LCD-PWR.4; also elsewhere on the board
unnamed: BC547.1 (B), R11.1
VEE: LCD-PWR.3, R12.2


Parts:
C3: 1µF; EIA3216
D1, D2, D3: MBR120VLSFT1G; SOD123
U1: TC1262-3.3VDB; SOT230P700X180-4N

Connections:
5V-NGC: D3.2 (A); also elsewhere on the board
5V-SNES: D2.2 (A); also elsewhere on the board
5V-USB: D1.2 (A); also elsewhere on the board
+3V3: C3.A (+), U1.3 (OUT); also elsewhere on the board
+5V: D1.1 (C), D2.1 (C), D3.1 (C), U1.1 (IN); also elsewhere on the board
GND: C3.C (-), U1.2 (GND), U1.4 (GND); also elsewhere on the board



Board: 2 copper layers, 101.7 x 66.5 mm, 40 parts (29 on the bottom side), 47 nets.

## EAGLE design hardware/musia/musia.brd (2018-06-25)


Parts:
C1, C2: 22pF; C0603
C7, C8, C9, C10, C11, C12: 0.1µF; C0603
CONN_SWD: H6X1; 1X06
JP-BOOT: PINHD-1X3; 1X03
LED1: GREEN; CHIPLED_0805
LED2: BLUE; CHIPLED_0805
LED3: RED; CHIPLED_0805
R1: 40k; R0603
R2, R3, R13: 330; R0603
R8: 10k; R0603
U$1: STM32F0425; LQFP48-STM32
U$4: 8mhz; ABM3B

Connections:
+3V3: C7.2, C8.2, C9.2, C10.2, C12.2, CONN_SWD.1, JP-BOOT.1, LED1.A, LED2.A, LED3.A, R1.1, U$1.1 (VBAT), U$1.9 (VDDA), U$1.24 (VDD), U$1.36 (VDDIO), U$1.48 (VDD); also elsewhere on the board
BOOT0: JP-BOOT.2, R8.2, U$1.44 (PF11)
EE#CS: U$1.38 (PA15); also elsewhere on the board
GND: C1.2, C2.2, C7.1, C8.1, C9.1, C10.1, C11.1, C12.1, CONN_SWD.3, JP-BOOT.3, R8.1, U$1.8 (VSSA), U$1.23 (VSS), U$1.35 (VSS), U$1.47 (VSS), U$4.2 (GND), U$4.4 (GND); also elsewhere on the board
JPS2_ACK: U$1.11 (PA1); also elsewhere on the board
JPS2_ATT: U$1.10 (PA0); also elsewhere on the board
LED1: R2.2, U$1.12 (PA2)
LED2: R3.2, U$1.13 (PA3)
LED3: R13.2, U$1.14 (PA4)
LED-GREEN: U$1.20 (PB2); also elsewhere on the board
LED-ORANGE: U$1.19 (PB1); also elsewhere on the board
unnamed: LED3.C, R2.1
unnamed: LED2.C, R13.1
unnamed: LED1.C, R3.1
unnamed: C2.1, U$1.6 (PF1), U$4.3 (2)
unnamed: C1.1, U$1.5 (PF0), U$4.1
NRST: C11.2, CONN_SWD.5, R1.2, U$1.7 (NRST)
PS2_VIBR_EN: U$1.4 (PC15); also elsewhere on the board
SPI1_CLK: U$1.15 (PA5); also elsewhere on the board
SPI1_MISO: U$1.16 (PA6); also elsewhere on the board
SPI1_MOSI: U$1.17 (PA7); also elsewhere on the board
SPI2_CLK: U$1.21 (PB10); also elsewhere on the board
SPI2_MISO: U$1.27 (PB14); also elsewhere on the board
SPI2_MOSI: U$1.28 (PB15); also elsewhere on the board
SWCLK: CONN_SWD.2, U$1.37 (PA14)
SWDIO: CONN_SWD.4, U$1.34 (PA13)
SW_CONSOLE_DISCONNECT: U$1.18 (PB0); also elsewhere on the board
SW_PULLUP_ENABLE: U$1.26 (PB13); also elsewhere on the board
SW_SNIFFER-CONSOLE: U$1.25 (PB12); also elsewhere on the board
SW_SPI_CLK: U$1.46 (PB9); also elsewhere on the board
USART1_RX: U$1.31 (PA10); also elsewhere on the board
USART1_TX: U$1.30 (PA9); also elsewhere on the board
USB_D+: U$1.33 (PA12); also elsewhere on the board
USB_D-: U$1.32 (PA11); also elsewhere on the board
USB_VIBR_EN: U$1.3 (PC14); also elsewhere on the board

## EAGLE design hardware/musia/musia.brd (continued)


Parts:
C6: 0.1µF; C0603
IC1: 25LC080SN; SO-08
R4, R9, R11, R12: 1k; R0603
R5: 1M; R0603
R6, R7: 0; R0603
U2: FSA2257; TSSOP14
U3, U4: TLP176AMSOP; SOP-4-2.54
U$3: NX2301P; SOT23

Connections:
+3V3: C6.2, IC1.3 (!WP), IC1.7 (!HOLD), IC1.8 (VCC), R4.2, U2.11 (VCC), U2.14 (VCC); also elsewhere on the board
+5V: U4.3 (D1); also elsewhere on the board
CPS2_VIBR: U3.3 (D1); also elsewhere on the board
EE#CS: IC1.1 (!CS); also elsewhere on the board
GND: C6.1, IC1.4 (GND), R5.2, U2.2 (GND), U2.5 (GND), U3.2 (K), U4.2 (K); also elsewhere on the board
JPS2_CLK: R7.2, U2.6 (2B0); also elsewhere on the board
JPS2_MISO: U2.1 (1A); also elsewhere on the board
JPS2_MOSI: R6.2; also elsewhere on the board
JPS2_VIBR: U3.4 (D2), U4.4 (D2); also elsewhere on the board
unnamed: R4.1, U$3.2 (S)
unnamed: R11.1, U3.1 (A)
unnamed: R9.2, U$3.1 (G)
unnamed: R12.1, U4.1 (A)
PS2_VIBR_EN: R11.2; also elsewhere on the board
SPI1_CLK: R7.1; also elsewhere on the board
SPI1_MISO: R5.1, U2.3 (1B0), U$3.3 (D); also elsewhere on the board
SPI1_MOSI: R6.1; also elsewhere on the board
SPI2_CLK: IC1.6 (SCK), U2.4 (2A); also elsewhere on the board
SPI2_MISO: IC1.2 (SO); also elsewhere on the board
SPI2_MOSI: IC1.5 (SI), U2.12 (1B1); also elsewhere on the board
SW_PULLUP_ENABLE: R9.1; also elsewhere on the board
SW_SNIFFER-CONSOLE: U2.13 (1S); also elsewhere on the board
SW_SPI_CLK: U2.10 (2S); also elsewhere on the board
USB_VIBR_EN: R12.2; also elsewhere on the board

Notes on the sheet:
Allow PS2 vibration signal to be disconnected from joystick
Selectable pull-up on MISO: usd when MCU is master. Disable when PS2 is master.
Protection 0-Ohms
Switch PS2 MISO line: * to SPI1 MISO when MCU is master * to SPI2 MOSI to console is master
Connect/disconnect SPI1 and SPI2 clock lines. Separate when accessing EEPROM on SPI2.


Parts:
C3, C4: 1µF; EIA3216
C5: 0.1µF; C0603
CONN-CPS: RJ45-NIELS
CONN-DBG: H3; 1X03
CONN-JPS: RJ45-NIELS
CONN-USB: USB-B-FEMALE; USB-B-H
D1, D2, D3: MBR120VLSFT1G; SOD123
PS2-JOYSTICK: PINHD-1X8; 1X08
R10: 10k; R0603
R16, R17: 220; R0603
U1: TC1262; SOT230P700X180-4N
U$2: SN74CB3Q3384; SSOP24

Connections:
5V-USB: CONN-USB.VBUS, D1.2 (A), D2.2 (A); also elsewhere on the board
+3V3: C3.A (+), C5.2, CONN-JPS.5, D3.1 (C), PS2-JOYSTICK.5, U1.3 (OUT), U$2.14 (2A1), U$2.15 (2B1), U$2.16 (2B2), U$2.17 (2A2), U$2.18 (2A3), U$2.19 (2B3), U$2.20 (2B4), U$2.21 (2A4), U$2.22 (2A5), U$2.23 (2B5), U$2.24 (VCC); also elsewhere on the board
+5V: C4.A (+), D1.1 (C), D2.1 (C), U1.1 (IN); also elsewhere on the board
CPS2-3V3: CONN-CPS.5, D3.2 (A)
CPS2_ACK: CONN-CPS.8, U$2.11 (1A5); also elsewhere on the board
CPS2_ATT: CONN-CPS.6, U$2.7 (1A3); also elsewhere on the board
CPS2_CLK: CONN-CPS.7, U$2.8 (1A4); also elsewhere on the board
CPS2_MISO: CONN-CPS.2, U$2.4 (1A2); also elsewhere on the board
CPS2_MOSI: CONN-CPS.1, U$2.3 (1A1); also elsewhere on the board
CPS2_VIBR: CONN-CPS.3; also elsewhere on the board
GND: C3.C (-), C4.C (-), C5.1, CONN-CPS.4, CONN-CPS.GND@5 (GND), CONN-CPS.GND@6 (GND), CONN-CPS.LED-GREEN-C (L2C), CONN-CPS.LED-ORANGE-C (L1C), CONN-DBG.3, CONN-JPS.4, CONN-JPS.GND@5 (GND), CONN-JPS.GND@6 (GND), CONN-USB.GND, CONN-USB.GND@1 (GND), CONN-USB.GND@2 (GND), PS2-JOYSTICK.4, R10.1, U1.2 (GND), U1.4 (GND), U$2.12 (GND); also elsewhere on the board
JPS2_ACK: CONN-JPS.8, PS2-JOYSTICK.8, U$2.10 (1B5); also elsewhere on the board
JPS2_ATT: CONN-JPS.6, PS2-JOYSTICK.6, U$2.6 (1B3); also elsewhere on the board
JPS2_CLK: CONN-JPS.7, PS2-JOYSTICK.7, U$2.9 (1B4); also elsewhere on the board
JPS2_MISO: CONN-JPS.2, PS2-JOYSTICK.2, U$2.5 (1B2); also elsewhere on the board
JPS2_MOSI: CONN-JPS.1, PS2-JOYSTICK.1, U$2.2 (1B1); also elsewhere on the board
JPS2_VIBR: CONN-JPS.3, PS2-JOYSTICK.3; also elsewhere on the board
LED-GREEN: R16.2; also elsewhere on the board
LED-ORANGE: R17.2; also elsewhere on the board
unnamed: CONN-CPS.LED-ORANGE-A (L1A), R17.1
unnamed: CONN-CPS.LED-GREEN-A (L2A), R16.1
SW_CONSOLE_DISCONNECT: R10.2, U$2.1 (1/OE), U$2.13 (2/OE); also elsewhere on the board
USART1_RX: CONN-DBG.1; also elsewhere on the board
USART1_TX: CONN-DBG.2; also elsewhere on the board
USB_D+: CONN-USB.D+; also elsewhere on the board
USB_D-: CONN-USB.D-; also elsewhere on the board

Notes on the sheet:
Fully disconnect console lines from joystick. Pull low while sniffing, high otherwise.
External RJ45 connection, joins special extension cord to console.
Internal RJ45 connection, joins PS2 controller to board.


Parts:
LOGICPORT: H5X2; 2X05
TP1, TP2, TP3, TP4, TP5, TP6, TP7, TP8, TP9, TP10, TP12, TP13, TP14, TP15, TP16, TP17, TP20, TP22, TP23: TPB1,27; B1,27

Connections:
5V-USB: TP23.TP; also elsewhere on the board
+3V3: TP22.TP; also elsewhere on the board
CPS2_ACK: TP9.TP; also elsewhere on the board
CPS2_ATT: TP1.TP; also elsewhere on the board
CPS2_CLK: TP4.TP; also elsewhere on the board
CPS2_MISO: TP3.TP; also elsewhere on the board
CPS2_MOSI: TP2.TP; also elsewhere on the board
CPS2_VIBR: TP15.TP; also elsewhere on the board
GND: LOGICPORT.9, LOGICPORT.10; also elsewhere on the board
JPS2_ACK: LOGICPORT.8, TP14.TP; also elsewhere on the board
JPS2_ATT: LOGICPORT.7, TP10.TP; also elsewhere on the board
JPS2_CLK: LOGICPORT.5, TP13.TP; also elsewhere on the board
JPS2_MISO: TP12.TP; also elsewhere on the board
JPS2_MOSI: LOGICPORT.1, TP5.TP; also elsewhere on the board
JPS2_VIBR: TP16.TP; also elsewhere on the board
SPI1_CLK: TP6.TP; also elsewhere on the board
SPI1_MISO: LOGICPORT.3, TP7.TP; also elsewhere on the board
SPI2_MISO: LOGICPORT.4; also elsewhere on the board
SPI2_MOSI: LOGICPORT.6, TP8.TP; also elsewhere on the board
SW_CONSOLE_DISCONNECT: TP20.TP; also elsewhere on the board
SW_SNIFFER-CONSOLE: TP17.TP; also elsewhere on the board

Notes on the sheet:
Collection of test points


Board: 2 copper layers, 100.0 x 66.5 mm, 69 parts (0 on the bottom side), 54 nets.

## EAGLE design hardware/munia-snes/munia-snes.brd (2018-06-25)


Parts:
C1: 100nF; C0603
C3: 1µF; EIA3216
PCB1: PCB_DP_RECTANGLE-43X70; DP7043_V1
PIC18F24K50: PIC18F2455_28W; SO28W
R10: 10k; R0603

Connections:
+5V: C1.1, PIC18F24K50.20 (VDD), R10.1; also elsewhere on the board
D+: PIC18F24K50.16 (RC5/D+/VP); also elsewhere on the board
D-: PIC18F24K50.15 (RC4/D-/VM); also elsewhere on the board
GND: C1.2, C3.C (-), PIC18F24K50.8 (VSS), PIC18F24K50.19 (VSS); also elsewhere on the board
JSNES-CLK: PIC18F24K50.9 (OSC1/CLKI); also elsewhere on the board
JSNES-DAT: PIC18F24K50.13 (RC2/CCP1/P1A); also elsewhere on the board
JSNES-LAT: PIC18F24K50.18 (RC7/RX/DT/SDO); also elsewhere on the board
LED1: PIC18F24K50.25 (RB4/AN11/KBI0/CSSPP); also elsewhere on the board
LED2: PIC18F24K50.22 (RB1/AN10/INT1/SCK/SCL); also elsewhere on the board
MCLR: PIC18F24K50.1 (!MCLR!/VPP/RE3), R10.2; also elsewhere on the board
unnamed: C3.A (+), PIC18F24K50.14 (VUSB)
PGC: PIC18F24K50.27 (RB6/KBI2/PGC); also elsewhere on the board
PGD: PIC18F24K50.28 (RB7/BKI3/PGD); also elsewhere on the board
PWR-LED: PIC18F24K50.2 (RA0/AN0); also elsewhere on the board
SWITCH1: PIC18F24K50.23 (RB2/AN8/INT2/VMO); also elsewhere on the board


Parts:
U1, U2: TS5A23166-VSSOP-8; SOT765

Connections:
+5V: U1.8 (V+), U2.8 (V+); also elsewhere on the board
CSNES-CLK: U2.1 (NO1); also elsewhere on the board
CSNES-DAT: U1.5 (NO2); also elsewhere on the board
CSNES-LAT: U1.1 (NO1); also elsewhere on the board
GND: U1.4 (GND), U2.4 (GND); also elsewhere on the board
JSNES-CLK: U2.2 (COM1); also elsewhere on the board
JSNES-DAT: U1.6 (COM2); also elsewhere on the board
JSNES-LAT: U1.2 (COM1); also elsewhere on the board
SWITCH1: U1.3 (IN2), U1.7 (IN1), U2.3 (IN2), U2.7 (IN1); also elsewhere on the board


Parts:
CONN-CSNES: RJ45-NIELS
CONN-JSNES: PINHD-1X5; 1X05
CONN-MENU: PINHD-1X3; 1X03
CONN-USB: USB-B-NIELS; USB-B-H
ICSP: PINHD-1X5; 1X05
R6, R8, R13: 10k; R0603
R14: 1k; R0603
R16, R17: 220; R0603

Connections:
5V-SNES: CONN-CSNES.1; also elsewhere on the board
+5V: CONN-JSNES.5, ICSP.4, R8.1, R13.1; also elsewhere on the board
CSNES-CLK: CONN-CSNES.2; also elsewhere on the board
CSNES-DAT: CONN-CSNES.4; also elsewhere on the board
CSNES-LAT: CONN-CSNES.3; also elsewhere on the board
D+: CONN-USB.D+; also elsewhere on the board
D-: CONN-USB.D-; also elsewhere on the board
GND: CONN-CSNES.8, CONN-CSNES.GND@5 (GND), CONN-CSNES.GND@6 (GND), CONN-CSNES.LED-GREEN-C (L2C), CONN-CSNES.LED-ORANGE-C (L1C), CONN-JSNES.1, CONN-MENU.1, CONN-USB.GND, CONN-USB.GND@1 (GND), CONN-USB.GND@2 (GND), ICSP.3, R6.1; also elsewhere on the board
JSNES-CLK: CONN-JSNES.2, R8.2; also elsewhere on the board
JSNES-DAT: CONN-JSNES.4, R13.2; also elsewhere on the board
JSNES-LAT: CONN-JSNES.3, R6.2; also elsewhere on the board
LED1: R17.2; also elsewhere on the board
LED2: R16.2; also elsewhere on the board
MCLR: CONN-MENU.3, ICSP.5; also elsewhere on the board
unnamed: CONN-MENU.2, R14.1
unnamed: CONN-CSNES.LED-ORANGE-A (L1A), R17.1
unnamed: CONN-CSNES.LED-GREEN-A (L2A), R16.1
PGC: ICSP.1; also elsewhere on the board
PGD: ICSP.2; also elsewhere on the board
PWR-LED: R14.2; also elsewhere on the board
VBUS: CONN-USB.VBUS; also elsewhere on the board


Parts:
D1, D2: MBR120VLSFT1G; SOD123

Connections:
5V-SNES: D2.2 (A); also elsewhere on the board
+5V: D1.1 (C), D2.1 (C); also elsewhere on the board
VBUS: D1.2 (A); also elsewhere on the board



Board: 2 copper layers, 70.0 x 43.0 mm, 20 parts (14 on the bottom side), 23 nets.

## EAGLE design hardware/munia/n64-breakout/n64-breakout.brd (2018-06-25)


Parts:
U$1, U$2, U$3, U$5, U$6, U$7: SMDPADSMD6080; SMD6080
U$4: N64-CONNECTOR

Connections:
DAT: U$2.P$1, U$4.DAT, U$6.P$1
GND: U$1.P$1, U$4.GND, U$7.P$1
VCC: U$3.P$1, U$4.VCC, U$5.P$1



Board: 2 copper layers, 17.8 x 16.5 mm, 7 parts (4 on the bottom side), 3 nets.

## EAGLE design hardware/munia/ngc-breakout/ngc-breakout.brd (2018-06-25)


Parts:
PAD_5V, PAD_5V1: SMD2; SMD1,27-2,54
PAD_DATA, PAD_DATA1: SMD2; SMD1,27-2,54
PAD_GND, PAD_GND1: SMD2; SMD1,27-2,54
U$1: NGC-CONNECTORGC-CONN2; NGC-CONNECTOR

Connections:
+5V: PAD_5V.1, PAD_5V1.1, U$1.1 (5V)
GND: PAD_GND.1, PAD_GND1.1, U$1.3 (GND), U$1.4 (GND), U$1.7 (GND)
unnamed: PAD_DATA.1, PAD_DATA1.1, U$1.2 (DATA)



Board: 2 copper layers, 15.9 x 11.9 mm, 7 parts (4 on the bottom side), 3 nets.

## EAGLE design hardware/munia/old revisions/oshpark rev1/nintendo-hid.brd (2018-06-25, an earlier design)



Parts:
C1, C6, C7, C8: 0.1µF; C0603
C9: 0.1µF; C0603K
C10: 470nF; C0603
FSA2257, FSA2257.: FSA2257MTCX; TSSOP14
OUT-UP: GTL2002D; SOIC127P600X175-8N
PIC18F24K50: PIC18F2455_28W; SO28W
R1: 220k; R0603
R2, R3: 2k2; R0603
R4: 200k; R0603
R10: 10k; R0603

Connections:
+3V3: OUT-UP.2 (SREF); also elsewhere on the board
+5V: C7.1, C8.1, C9.1, FSA2257.11 (VCC), FSA2257.14 (VCC), FSA2257..11 (VCC), FSA2257..14 (VCC), PIC18F24K50.20 (VDD), R2.2, R3.2, R4.1, R10.1; also elsewhere on the board
D4: PIC18F24K50.5 (RA3/AN3/VREF+); also elsewhere on the board
D5: PIC18F24K50.4 (RA2/AN2/VREF-/CVREF); also elsewhere on the board
D6: PIC18F24K50.3 (RA1/AN1); also elsewhere on the board
D7: PIC18F24K50.2 (RA0/AN0); also elsewhere on the board
D+: PIC18F24K50.16 (RC5/D+/VP); also elsewhere on the board
D-: PIC18F24K50.15 (RC4/D-/VM); also elsewhere on the board
E: PIC18F24K50.6 (RA4/T0CKI/CIOUT/RCV); also elsewhere on the board
FAKE_3V3.1: FSA2257.6 (2B0), OUT-UP.4 (S2)
FAKE_3V3.2: FSA2257..3 (1B0), OUT-UP.3 (S1)
FAKE_5V: FSA2257.3 (1B0), OUT-UP.5 (D2), OUT-UP.6 (D1), PIC18F24K50.24 (RB3/AN9/CCP2/VPO), R2.1, R3.1
GND: C1.1, C6.2, C7.2, C8.2, C9.2, C10.2, FSA2257.2 (GND), FSA2257.5 (GND), FSA2257..2 (GND), FSA2257..5 (GND), FSA2257..10 (2S), OUT-UP.1 (GND), PIC18F24K50.8 (VSS), PIC18F24K50.19 (VSS); also elsewhere on the board
J64-DAT-5V: PIC18F24K50.12 (RC1/T1OSI/ICCP2/!UOE)
J64_DAT: FSA2257.9 (2B1); also elsewhere on the board
JGC-DAT-5V: PIC18F24K50.11 (RC0/TIOSO/T13CKI)
JGC_DAT: FSA2257..12 (1B1); also elsewhere on the board
JSNES_DAT: FSA2257.12 (1B1)
LCD_PWM: PIC18F24K50.26 (RB5/KBI1/PGM); also elsewhere on the board
MCLR: PIC18F24K50.1 (!MCLR!/VPP/RE3), R10.2; also elsewhere on the board
unnamed 28: FSA2257.4 (2A); also elsewhere on the board
unnamed 34: FSA2257..1 (1A); also elsewhere on the board
unnamed: C10.1, PIC18F24K50.14 (VUSB)
unnamed: C6.1, OUT-UP.7 (DREF), OUT-UP.8 (GREF), R4.2
unnamed 41: PIC18F24K50.17 (RC6/TX/CK); also elsewhere on the board
PGC: PIC18F24K50.27 (RB6/KBI2/PGC); also elsewhere on the board
PGD: PIC18F24K50.28 (RB7/BKI3/PGD); also elsewhere on the board
RS: PIC18F24K50.25 (RB4/AN11/KBI0/CSSPP); also elsewhere on the board
S1: FSA2257.13 (1S), PIC18F24K50.23 (RB2/AN8/INT2/VMO)
S2: FSA2257.10 (2S), PIC18F24K50.22 (RB1/AN10/INT1/SCK/SCL)
S3: FSA2257..13 (1S), PIC18F24K50.21 (RB0/AN12/INT0/LFT0/SDI/SDA)
SNES_CLK: PIC18F24K50.9 (OSC1/CLKI); also elsewhere on the board
SNES_LATCH: PIC18F24K50.10 (RA6/OSC2/CLKO); also elsewhere on the board
SNES_OUT: FSA2257.1 (1A); also elsewhere on the board
USB-SENSE: PIC18F24K50.18 (RC7/RX/DT/SDO), R1.2
VBUS: C1.2, R1.1


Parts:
C64: RJ11-6P4C; RJ11-4C
ICSP: PINHD-1X5; 1X05
J64: PINHD-1X3; 1X03
JGC: PINHD-1X6; 1X06
JSNES: PINHD-1X5; 1X05
R7, R9, R16, R17: 220; R0603
U$1, U$2: RJ45-NIELS
X1: USB-B-NIELS; USB-B-H

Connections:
5V-USB: X1.VBUS; also elsewhere on the board
+3V3: J64.1, JGC.5; also elsewhere on the board
+5V: ICSP.4, JGC.6, JSNES.5; also elsewhere on the board
CSNES_5V: U$1.6
D+: X1.D+; also elsewhere on the board
D-: X1.D-; also elsewhere on the board
GND: C64.3, C64.4, ICSP.3, J64.3, JGC.1, JGC.2, JGC.3, JSNES.1, U$1.GND@5 (GND), U$1.GND@6 (GND), U$1.LED-GREEN-C (L2C), U$1.LED-ORANGE-C (L1C), U$2.2, U$2.3, U$2.4, U$2.5, U$2.GND@5 (GND), U$2.GND@6 (GND), U$2.LED-GREEN-C (L2C), U$2.LED-ORANGE-C (L1C), X1.GND, X1.GND@1 (GND), X1.GND@2 (GND); also elsewhere on the board
J64_DAT: J64.2; also elsewhere on the board
JGC_DAT: JGC.4; also elsewhere on the board
MCLR: ICSP.5; also elsewhere on the board
unnamed 28: C64.2; also elsewhere on the board
unnamed: R9.1, U$2.LED-ORANGE-A (L1A)
unnamed 34: U$2.6; also elsewhere on the board
unnamed 41: U$1.7; also elsewhere on the board
unnamed: R7.1, U$2.LED-GREEN-A (L2A)
PGC: ICSP.1; also elsewhere on the board
PGD: ICSP.2; also elsewhere on the board
SNES_CLK: U$1.5; also elsewhere on the board
SNES_LATCH: U$1.4; also elsewhere on the board
SNES_OUT: U$1.3; also elsewhere on the board

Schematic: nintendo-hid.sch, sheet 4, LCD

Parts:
BC547: BC547; TO92
LCD-DATA: PINHD-1X8; 1X08
LCD-PWR: PINHD-1X4; 1X04
R11: 1k; R0603
R12, R13: 20k; R0603

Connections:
+5V: LCD-DATA.2, LCD-PWR.2, R13.2; also elsewhere on the board
C: BC547.3 (C), LCD-DATA.1
D4: LCD-DATA.6; also elsewhere on the board
D5: LCD-DATA.5; also elsewhere on the board
D6: LCD-DATA.4; also elsewhere on the board
D7: LCD-DATA.3; also elsewhere on the board
E: LCD-DATA.7; also elsewhere on the board
GND: BC547.1 (E), LCD-DATA.8, LCD-PWR.1, R12.1; also elsewhere on the board
LCD_PWM: R11.2; also elsewhere on the board
unnamed: BC547.2 (B), R11.1
RS: LCD-PWR.4; also elsewhere on the board
VEE: LCD-PWR.3, R12.2, R13.1

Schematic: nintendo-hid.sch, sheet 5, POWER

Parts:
C2, C3: 0.1µF; C0603
D1, D2, D3: MBR120VLSFT1G; SOD123
U1: TC1262-3.3VDB; SOT230P700X180-4N

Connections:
5V-NGC: D3.2 (A)
5V-SNES: D2.2 (A)
5V-USB: D1.2 (A); also elsewhere on the board
+3V3: C3.1, U1.3 (OUT); also elsewhere on the board
+5V: C2.1, D1.1 (C), D2.1 (C), D3.1 (C), U1.1 (IN); also elsewhere on the board
GND: C2.2, C3.2, U1.2 (GND), U1.4 (GND); also elsewhere on the board



Board: 2 copper layers, 116.0 x 67.5 mm, 39 parts (22 on the bottom side), 39 nets.

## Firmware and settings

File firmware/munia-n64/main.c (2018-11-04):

#include "system_config.h"
#include <usb/usb.h>
#include <usb/usb_device_hid.h>
#include <stdlib.h>
#include "hardware.h"
#include "globals.h"
#include "n64.h"
#include "gamepad.h"
#include "memory.h"
#include "report_descriptors.h"
#include "usb_requests.h"
#include "config.h"

void init_pll();
void init_io();
void init_timers();
void init_interrupts();

void load_config();
void apply_config();
void save_config();
void load_device_id();

uint8_t counter60hz = 0;
config_t config;

void usb_tasks();

void main() {
    init_io();
    init_pll();        
    init_timers();
    usb_descriptors_check();
	USBDeviceInit();
    USBDeviceAttach();
    
    load_config();    
    apply_config();
    init_interrupts();    
    
    memset(usbOutBuffer, 0, sizeof(usbOutBuffer));
    memset(usbInBuffer, 0, sizeof(usbInBuffer));
    
	while (1) {
        ClrWdt();                
        USBDeviceTasks();
        
        if (PIR2bits.TMR3IF) {
            WRITETIMER3(15536);
            PIR2bits.TMR3IF = 0;
            pollNeeded = true;
        }
        
        n64_tasks();        
        usb_tasks();
        pollNeeded = false;
    }
}

void init_pll() {
	OSCTUNE = 0x80; // 3X PLL ratio mode selected
	OSCCON = 0x70;  // Switch to 16MHz HFINTOSC
	OSCCON2 = 0x10; // Enable PLL, SOSC, PRI OSC drivers turned off
#ifndef SIMUL    
	while (!OSCCON2bits.PLLRDY); // Wait for PLL lock
#endif
	ACTCON = 0x90;  // Enable active clock tuning for USB operation
}

void init_io() {
    // analog ports
	ANSELA = 0b00000000; // all digital
	ANSELB = 0b00000000;
	ANSELC = 0b00000000;
    
    // io directions
    TRISA = 0b11000000; // RA0-4 for LCD, RA5 for led, RA6/7 snes LATCH/CLOCK
    TRISB = 0b00000000; // outputs for leds, LCD, fake signal, switches
    TRISC = 0b10000111; // usb sense, uart tx, snes/n64/gc input signals

    // pull ups on the inputs
    LATA |= 0b11000000;
    LATC |= 0b10000111;

    ADCON0bits.ADON = 0;
}

void init_timers() {
    // Timer 0: used for packet capture timeout detection
    //   Speed is FOSC
    //   Reset when starting packet sample, or new bit received
    //   Once IF set, packet sample has finished
    // Timer 1: count packet length during NGC/N64 sampling
    // Timer 2: source at 1KHz, for EasyTimer
    // Timer 3: polling indicator, runs either at 50Hz or 60Hz
    
    
	// Timer0 as 8-bit 1:1 on instruction clock
	INTCONbits.TMR0IE = 0; // Disables the TMR0 overflow interrupt
	T0CONbits.TMR0ON = 1; // Enables Timer0
	T0CONbits.T08BIT = 1; // Timer0 is configured as an 8-bit timer/counter
	T0CONbits.T0CS = 0; // Instruction clock (FOSC/4)
	T0CONbits.PSA = 1; // Timer0 prescaler is NOT assigned. 
    
    // Timer 1 counts during n64/ngc sampling
    T1CONbits.TMR1CS = 0b00; // clock source is instruction clock (FOSC/4)
    T1CONbits.T1CKPS = 0b00; // 1:1 prescaler
    T1CONbits.SOSCEN = 0; // 0 = Dedicated secondary oscillator circuit disabled
    T1CONbits.RD16 = 0; // 0 = Dedicated secondary oscillator circuit disabled
	PIE1bits.TMR1IE = 0; // Disables the TMR1 overflow interrupt
    T1CONbits.TMR1ON = 1; // start
    
    // Timer3 Registers Prescaler= 4 - TMR3 Preset = 15536 - Freq = 60.00 Hz - Period = 0.016667 seconds
    T3CONbits.TMR3CS = 0b00; // clock source is instruction clock (FOSC/4)
    T3CONbits.T3CKPS = 0b10; // 1:1 prescaler
    PIE2bits.TMR3IE = 0; // Disable interrupt
    T3CONbits.TMR3ON = 1; // Start timer
    WRITETIMER3(15536);
}

void init_interrupts() {
	// setup interrupt on falling change of data on gamepad ports
	INTCONbits.IOCIE = 1; // IOC interrupt enabled
	INTCON2bits.IOCIP = 1; // High priority group
    
	RCONbits.IPEN = 1; // Enable priority levels on interrupts
	INTCONbits.GIEH = 1; // Enable high priority interrupts
	INTCONbits.GIEL = 1; // Enable low priority interrupts
}


void load_config() {
    uint8_t* w = (uint8_t*)&config;
    for (uint8_t i = 0; i < sizeof(config); i++)
        *w++ = ee_read(i);
}

void save_config() {
    uint8_t* r = (uint8_t*)&config;
    for (uint8_t i = 0; i < sizeof(config); i++)
        ee_write(i, *r++);
}

void apply_config() {
    // validate
    if (config.output_mode >= output_pc) config.output_mode = output_pc;
    else config.output_mode = output_n64;
    config.input_sources &= input_n64;
    
    // only take interrupt event from the console we're outputting to
    IOCCbits.IOCC1 = config.output_mode == output_n64;
    
    // redirect joysticks we're not sampling to their console
    // switch position = 0 --> connected to our fake output,
    //                   1 --> connected to joystick
    SWITCH2 = IOCCbits.IOCC1 || !config.input_n64;
}

void randomize_device_id() {    
    // setup adc
    ADCON1bits.PVCFG    = 0b00; // set v+ reference to Vdd
    ADCON1bits.NVCFG    = 0b0;  // set v- reference to GND
    ADCON2bits.ADFM     = 0b1;  // right justify the output
    ADCON2bits.ACQT     = 0b110;// 16 TAD
    ADCON2bits.ADCS     = 0b101;// use Fosc/16 for clock source
    ADCON0bits.ADON     = 0b1;  // turn on the ADC

    // generate random serial, seeded with xor of 16 readings of ADC
    // (Performing a conversion on unimplemented channels will return random values.)
    unsigned int seed = 0x3F07 ^ TMR0; // poly
    ADCON0bits.CHS = 0b11011; // select analog input channel 27 (unimplemented))
    
    for (int i = 0; i < 8; i++) {
        ADCON0bits.GO = 0b1; // start the conversion
        while(ADCON0bits.DONE); // wait for the conversion to finish
        seed ^= (ADRESH << 8) | ADRESL;  // return the result
    }
    ADCON0bits.ADON = 0;  // turn off the ADC
    srand(seed); // seed with conversion result

    uint8_t* w = (uint8_t*)&deviceID;
    *w++ = rand();
    *w++ = rand();
    *w++ = rand();
    *w++ = rand();
    ADCON0bits.ADON = 0;  // turn off the ADC
}

void load_device_id() {
    uint8_t* r = (uint8_t*)&deviceID;
    for (uint8_t i = 0x20; i < 0x24 ; i++)
        *r++ = ee_read(i);

    if (deviceID == 0 || deviceID == 0xFFFFFFFF) {
        // generate random device id, and save it
        randomize_device_id();
        uint8_t* w = (uint8_t*)&deviceID;   
        for (uint8_t i = 0x20; i < 0x24 ; i++){            
            ee_write(i, *w++);
        }
    }
}

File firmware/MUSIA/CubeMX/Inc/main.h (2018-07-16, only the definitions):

#define MENU_ALT_Pin GPIO_PIN_13
#define MENU_ALT_GPIO_Port GPIOC
#define LCD_PWM_Pin GPIO_PIN_14
#define LCD_PWM_GPIO_Port GPIOC
#define PS2_VIBR_EN_Pin GPIO_PIN_15
#define PS2_VIBR_EN_GPIO_Port GPIOC
#define JPS2_ATT_Pin GPIO_PIN_0
#define JPS2_ATT_GPIO_Port GPIOA
#define JPS2_ACK_Pin GPIO_PIN_1
#define JPS2_ACK_GPIO_Port GPIOA
#define LED1_Pin GPIO_PIN_2
#define LED1_GPIO_Port GPIOA
#define LED2_Pin GPIO_PIN_3
#define LED2_GPIO_Port GPIOA
#define LED3_Pin GPIO_PIN_4
#define LED3_GPIO_Port GPIOA
#define SW_CONSOLE_DISCONNECT_Pin GPIO_PIN_0
#define SW_CONSOLE_DISCONNECT_GPIO_Port GPIOB
#define LED_ORANGE_Pin GPIO_PIN_1
#define LED_ORANGE_GPIO_Port GPIOB
#define LED_GREEN_Pin GPIO_PIN_2
#define LED_GREEN_GPIO_Port GPIOB
#define SW_SNIFFER_CONSOLE_Pin GPIO_PIN_12
#define SW_SNIFFER_CONSOLE_GPIO_Port GPIOB
#define SW_PULLUP_ENABLE_Pin GPIO_PIN_13
#define SW_PULLUP_ENABLE_GPIO_Port GPIOB
#define EE_CS_Pin GPIO_PIN_15
#define EE_CS_GPIO_Port GPIOA
#define LCD_D7_Pin GPIO_PIN_3
#define LCD_D7_GPIO_Port GPIOB
#define LCD_D6_Pin GPIO_PIN_4
#define LCD_D6_GPIO_Port GPIOB
#define LCD_D5_Pin GPIO_PIN_5
#define LCD_D5_GPIO_Port GPIOB
#define LCD_D4_Pin GPIO_PIN_6
#define LCD_D4_GPIO_Port GPIOB
#define LCD_E_Pin GPIO_PIN_7
#define LCD_E_GPIO_Port GPIOB
#define MENU_Pin GPIO_PIN_11
#define MENU_GPIO_Port GPIOF
#define LCD_RS_Pin GPIO_PIN_8
#define LCD_RS_GPIO_Port GPIOB
#define SW_SPI_CLK_Pin GPIO_PIN_9
#define SW_SPI_CLK_GPIO_Port GPIOB

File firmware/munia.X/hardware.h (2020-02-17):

#ifndef HARDWARE_H
#define	HARDWARE_H

#define HW_REVISION 2

#define _XTAL_FREQ 48000000

#define SNES_DAT PORTCbits.RC2
#define SNES_LATCH PORTCbits.RC7
#define SNES_CLK PORTAbits.RA7
#define N64_DAT PORTCbits.RC1
#define NGC_DAT PORTCbits.RC0

#define SNES_DAT_TRIS TRISCbits.TRISC2
#define SNES_LATCH_TRIS TRISCbits.TRISC7
#define SNES_CLK_TRIS TRISAbits.TRISA7
#define N64_DAT_TRIS TRISCbits.TRISC1
#define NGC_DAT_TRIS TRISCbits.TRISC0

#define LED_SNES_GREEN LATAbits.LATA5
#define LED_SNES_ORANGE LATCbits.LATC6
#define LED_GC_GREEN LATBbits.LATB6
#define LED_GC_ORANGE LATBbits.LATB7

#define FAKE_DAT LATBbits.LATB3

#define LCD_RS LATBbits.LATB4
#define LCD_PWM LATBbits.LATB5
#define LCD_E LATAbits.LATA4

#if HW_REVISION == 1
#define SWITCH3 LATBbits.LATB2 // for ngc
#define SWITCH2 LATBbits.LATB1 // for n64
#define SWITCH1 LATBbits.LATB0 // for snes
#define LCD_D4 LATAbits.LATA0
#define LCD_D5 LATAbits.LATA1
#define LCD_D6 LATAbits.LATA2
#define LCD_D7 LATAbits.LATA3
#elif HW_REVISION == 2
#define SWITCH1 LATBbits.LATB2 // for ngc
#define SWITCH2 LATBbits.LATB1 // for n64
#define SWITCH3 LATBbits.LATB0 // for snes
//#define LCD_SWAPPED 1
#endif


#define BUTTON_COUNT 1
#define BUTTON_0 BTN_MENU
#define BTN_MENU (!PORTEbits.RE3)
#define BTN_MENU_PRESSED bcPressed[0]

#endif	/* HARDWARE_H */

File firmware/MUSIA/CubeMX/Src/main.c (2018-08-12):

/**
  ******************************************************************************
  * @file           : main.c
  * @brief          : Main program body
  ******************************************************************************
  ** This notice applies to any and all portions of this file
  * that are not between comment pairs USER CODE BEGIN and
  * USER CODE END. Other portions of this file, whether 
  * inserted by the user or by software development tools
  * are owned by their respective copyright owners.
  *
  * COPYRIGHT(c) 2018 STMicroelectronics
  *
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
  ******************************************************************************
  */
/* Includes ------------------------------------------------------------------*/
#include "main.h"
#include "stm32f0xx_hal.h"
#include "dma.h"
#include "iwdg.h"
#include "tim.h"
#include "usart.h"
#include "gpio.h"


/* USER CODE BEGIN PV */

/* USER CODE END PV */

void SystemClock_Config(void);

/* USER CODE BEGIN PFP */
void bootloaderSwitcher();
void musia_main();
/* USER CODE END PFP */

/**
  * @brief  The application entry point.
  *
  * @retval None
  */
int main(void)
{
  /* USER CODE BEGIN 1 */
	bootloaderSwitcher();
  /* USER CODE END 1 */

  /* MCU Configuration----------------------------------------------------------*/

  /* Reset of all peripherals, Initializes the Flash interface and the Systick. */
  HAL_Init();

  /* Configure the system clock */
  SystemClock_Config();

  /* USER CODE BEGIN SysInit */
 __HAL_RCC_DBGMCU_CLK_ENABLE();
 // __HAL_DBGMCU_FREEZE_IWDG();
  /* USER CODE END SysInit */

  /* Initialize all configured peripherals */
  MX_GPIO_Init();
  MX_DMA_Init();
  MX_IWDG_Init();
  MX_USART1_UART_Init();
  MX_TIM1_Init();
  /* Infinite loop */
  /* USER CODE BEGIN WHILE */
  while (1)
  {

  /* USER CODE END WHILE */

  /* USER CODE BEGIN 3 */
	 musia_main();
  }
  /* USER CODE END 3 */

}

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


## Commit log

2015-06-16 update BOM
    [ninhid.xlsx]
2015-06-16 fully working config for 1 device
2015-06-18 remove backlight pwm stuff from lcd lib
2015-06-23 add circular buffer and button checker
2015-06-23 disable backlight on powerup
2015-06-25 more useful leds
2015-07-20 bom update
    [ninhid.xlsx]
2015-12-31 mark current selection when changing menu page
2015-12-31 backup for swapped wires
2015-12-31 update excel, add wiring schematics
    [munia.xlsx, ninhid.xlsx]
2016-04-14 update cable schematics
    [munia.xlsx]
2016-04-15 find smallest enclosing button, enable alpha blends
2016-04-18 remove unused z-axis stuff and fix scaling issue
2016-04-18 rebuild menu upon USB device changes
2016-04-21 allow viewing in debug mode without attached device
2016-04-22 upgrade USB framework
2016-04-23 add some uart debugging capabilities
2016-05-08 add PIC device id / revision to config interface
2016-05-08 properly separate skins, svg controllers and input devices
2016-07-09 add device id/revision to config report
2016-07-17 refactored stuff to allow for expansion with arduino controllers and padpyght skins
2016-08-20 multi-device support, mostly implements #10
2016-08-21 change skins to use 'device-type' instead of 'device-name' for controller matching
2016-08-21 implement the 3 arduino controller packets, closes #14
2016-08-21 save arduino --> joystick mapping
2016-08-21 implement arduino controller base class, refs #7
2016-08-26 introduce 'hats' (can be copy of buttons)
2016-10-01 disable debug-incompatible fuses for debug runs
2016-10-02 add interrupt remap for debug build (normally taken care of by bootloader)
2016-10-02 sample gamecube in assembly
2016-10-02 sample n64 in assembly
2016-10-02 sample snes in assembly
2016-10-02 add assembly project for isr joystick sampling
2016-10-02 use bitfields for available packets instead of separate variables
    Former-commit-id: 683e3c8199718fe12ed3055639ffdb6843220190
    [assembly steps.xlsx]
2016-10-02 remove C interrupt routine
    Former-commit-id: 0d8411cf370906eb75b9a9b2ec91b310130890b9
2016-10-02 project update
    Former-commit-id: a4468454f4e4c02308eeb1ad7ce68533b0965506
    [munia.xlsx]
2016-10-02 reconnect to disconnected device after reattaching it
2016-10-02 put z-button behind controller base
2016-10-03 tighten memory
    Former-commit-id: 935519d7d0fbb151815fc007cd7b0ce02189ed0c
2016-10-03 print signed debug value
    Former-commit-id: 5310482e42827c3479da6cfc6914ce442bbe270f
2016-10-05 use raw packets instead of usb packets as source for fakes; fix some output bugs
    Former-commit-id: 3c4f54f7f07c3a8f4a848cb793523c5721470ae6
    [main.c]
2016-10-31 mini fix
    Former-commit-id: dbdb2dcda0dae7e5968d624a6e41486936f4d516
    [main.c]
2016-11-12 document steps
    Former-commit-id: 67a05e6816085424f93e0b6b2d01d3923cb22b5d
    [assembly steps.xlsx]
2016-11-20 Use predicted name in case USB device names are messed up
    Former-commit-id: a34c3342c3724b2f2ac48b92ff3ff37b20c33a64
2016-11-20 fix button/axes mappings
    Former-commit-id: ab98c924d0805d804fda73b0c9d5cf61823e946b
2017-07-29 update wiring
    Former-commit-id: d2d997aec763ce4fe44edb830d331a0720604a7d
    [munia.xlsx]
2017-08-10 device-specific settings
    Former-commit-id: 336f3215b61132eb132ef60bd8f6774f3c1ddbb1
2017-08-10 MUNIA-NGC firmware
    Former-commit-id: 6778e9d066cad8a99dd5226e2041045da585b1e7
    [munia.xlsx]
2017-11-12 New N64 skin. Basically a rework of the included one, but square in shape and with a Z button.
    Former-commit-id: 108394e9e2cf4edc07fd7ae1906dd8a040c2b1d6
2017-12-09 Delete old wiring sch.png
    Former-commit-id: 4bf18670e82be16b4dcd22c61135777f16cd9ccc
2018-06-24 organize files
    Former-commit-id: 2a5ad49bad332abe6839f00f9073f808990ce24f
    [MUNIA assembly.xlsx, munia.xlsx]
2018-06-25 minimal BSP glue
    Former-commit-id: e8d3ed6695984236683366bf08959afc7917123b
2018-06-25 remove traces of STM's USB stack
    Former-commit-id: 4ca9e43ab7999f90e73fb9982d99398442fa8fe8
2018-06-25 add schematics for all devices thus far
    Former-commit-id: 480aa2b86be94b459dd1aec146da21080f2f386a
    [munia-n64.brd, munia-n64.sch, munia-ngc.brd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]
2018-06-25 move
    Former-commit-id: 9f13b57de49d63ce73473e654a88a006a95b2b32
    [MUNIA assembly.xlsx]
2018-06-27 support pressable sticks linked to buttons
    Former-commit-id: e643b41ca40940214ab281d1b604c2975f2584aa
2018-06-27 poller framework
    Former-commit-id: 37f74f04a5b11642b713be8cc82be120cf0c7d93
2018-06-27 usb pid force feedback structs definitions
    Former-commit-id: f3c67ac22d6a0a4c9a862bdd0473870ce0cb7a57
2018-06-27 debug print stub
    Former-commit-id: 94055ad8a00939abb7dcdb9b17b9c753172f6a04
2018-06-27 fix spi init sequence
    [musia.cpp]
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2018-06-27 pass in state, allow to track different states
2018-06-27 fail-safe GPIO init values
    [MUSIA.ioc]
2018-06-27 correct SPI init sequences for eeprom, poller, sniffer
    [musia.cpp]
2018-06-29 force USB init reset, in case bootloader didnt release cleanly
    [musia.cpp]
2018-06-29 multi-device and ps2 device support
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2018-07-01 fix possible buffer overflow after interrupted sniffing DMA
2018-07-01 printf_payload only in DEBUG
2018-07-01 implement runtime config switching
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2018-07-11 remove USB vibration idea
    [main.h]
2018-07-11 jump to correct bootloader depending on device id
2018-07-14 simplified button checker for only 1 button
2018-07-14 remove printf from debug
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2018-07-17 identified another type of snes extension
    [munia.xlsx]
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2018-08-01 buy button on main page
2018-08-02 z-index missing on snes non-pressed buttons
2018-08-12 add ps2 pinout
    [munia.xlsx]
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2018-09-29 debug print fix
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2018-09-29 set correct PIC18 LF device
2018-11-04 new cable type
    [munia.xlsx]
2018-11-21 correct trigger mapping for NGC arduino controller
2018-11-21 Add support for NintendoSpy triggers, 'detail' items, range buttons and scaling attributes
2018-11-25 correct case
2018-11-25 dynamically enable test buttons
2018-12-24 add support for remapping MUNIA and Arduino controllers as well
2018-12-24 since IsAvailable is now used for menu filtering, make sure its result is correct
2018-12-24 rangebuttons apply over axes, not buttons
2018-12-24 add button to set window size to skin default
2019-02-12 fix one too many items removed from source buttons list
2019-03-25 Fix issue where buffered controller uses 'real' device state instead of mapped state
2019-04-17 don't crash on invalid arduino controller type
2019-05-20 Support MUSIA controllers that report pressure sensor values
2019-05-20 update wiring document
    [munia.xlsx]
2019-05-20 fix pressure sensor count to 12
2020-06-26 update rev2 with power from console
    [munia-n64.brd, munia-n64.sch]
2020-06-26 Add missing printf-stdarg files
2020-06-26 For playstation menu, use 'X' instead of Nintendo's 'A' for menu confirm button
2020-12-13 fix dpad button assignments for xbone skin
2020-12-13 prevent xinput devices from showing twice in controller listing

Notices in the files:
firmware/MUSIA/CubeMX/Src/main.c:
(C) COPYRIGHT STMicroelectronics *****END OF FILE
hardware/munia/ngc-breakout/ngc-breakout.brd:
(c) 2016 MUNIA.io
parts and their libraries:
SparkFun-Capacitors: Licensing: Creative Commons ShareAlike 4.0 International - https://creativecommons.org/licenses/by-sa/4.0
